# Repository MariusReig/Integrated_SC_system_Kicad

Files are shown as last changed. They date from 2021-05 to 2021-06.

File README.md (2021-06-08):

# Integrated_SC_system_Kicad
This repository contains the schematics and layout for an integrated supercapacitor system design.

Some changes is done in the schematic after the prototype was constructed. This includes:
- Removed schotky diode and auto-balancing in the cell balancing circuitry. 
- Adjusted cell-balancing resistance. 
- Adjusted pull-up resistor in the OVP. This is also done to the prototype.
- Charge and pre-charge gate-signal on isolated end is switched. 

Notes from testing of the prototype:
- The prototype is able to charge without any gatesignal through the pre-charge mosfet. Gatesignal is required to utilize charge and load. 
- The auto-balancing IC does not work as intended. Seems to be working for one cell of the two connected for each. Go back and check connections or use only resistor balancing. 
The design with balancing two-and-two cells is not great and needs work. Also caused the voltage potential over some odd-number cells to become negative. The voltage potential over the two first cells affected another, causing the even cell to receive more charge. A quick fix was to remove the IC and solder on 160ohm balancing resistance for each cell. The prototype was then balanced properly and tests was carried out. 
- The schotky diode was removed to test if it was a potential error-source. It was not. 
- The OVP circuit did not work. Since all 12 circuits are connected to the same 5V_ISO supply all will be pulled to ground unless all are active at the same time. The differential amplifier works as intended, but not the votlage detection IC. Tests on the IC can be carried out to check if it works as designed.

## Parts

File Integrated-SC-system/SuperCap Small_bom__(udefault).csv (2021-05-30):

Component | Description | Part | References | Value | Footprint | Quantity Per PCB | Datasheet | Mouser Part Number | Mouser Price/Stock | Manufacturer_Name | Height | Manufacturer_Part_Number | Arrow Part Number | Arrow Price/Stock
1 | Unpolarized capacitor | C | C2 C5 C11 C12 C15 | 100p | C_1206_3216Metric_Pad1.33x1.80mm_HandSolder | 5 | ~ | 581-12063A101FAT2A | https://no.mouser.com/ProductDetail/AVX/12063A101FAT2A?qs=Y1%2F2wzs%252B63syfZuGtnXFwA%3D%3D
2 | Unpolarized capacitor | C | C19 | 330p | C_1206_3216Metric_Pad1.33x1.80mm_HandSolder | 1 | ~ | 80-C1206C331F3HACTU | https://no.mouser.com/ProductDetail/KEMET/C1206C331F3HACTU?qs=W0yvOO0ixfE2Qm7oN9qcZQ%3D%3D
3 | Unpolarized capacitor | C | C14 | 430p | C_1206_3216Metric_Pad1.33x1.80mm_HandSolder | 1 | ~ | 77-VJ12A100V431J | https://no.mouser.com/ProductDetail/Vishay-Vitramon/VJ1206A431JXBAT/?qs=sbOXSeWPT5yYapLoCJrwWA%3D%3D
4 | Unpolarized capacitor | C | C6 | 470p | C_1206_3216Metric_Pad1.33x1.80mm_HandSolder | 1 | ~ | 80-C1206C471F5G | https://no.mouser.com/ProductDetail/KEMET/C1206C471F5GACTU?qs=slLRK711bwGFkpel8EAHvQ%3D%3D
5 | Unpolarized capacitor | C | C1 C4 C7 C9 C13 | 0.01u | C_1206_3216Metric_Pad1.33x1.80mm_HandSolder | 5 | ~ | 80-C1206C103F3GECAUT | https://no.mouser.com/ProductDetail/KEMET/C1206C103F3GECAUTO?qs=MLItCLRbWszn6w2I8I0T6g%3D%3D
6 | Unpolarized capacitor | C | C17 C20 C22 C36 C37 C38 C39 C40 C41 C42 C43 C44 C45 C46 C47 C48 C49 C50 C51 C52 C53 C54 C55 C56 C57 C58 C59 C60 C61 C62 C63 C64 C65 C66 C67 C68 C69 C70 C71 C72 C73 C74 C75 C76 C77 C78 C79 C80 C81 C82 | 0.1u | C_1206_3216Metric_Pad1.33x1.80mm_HandSolder | 50 | ~ | 80-C1206C104F5JACTU | https://no.mouser.com/ProductDetail/KEMET/C1206C104F5JAC7800?qs=gZXFycFWdAOIF48nFZgPGA%3D%3D
7 | Unpolarized capacitor | C | C3 C18 C21 C23 C83 C84 | 1u | C_1206_3216Metric_Pad1.33x1.80mm_HandSolder | 6 | ~ | 80-C1206C105J3R | https://no.mouser.com/ProductDetail/KEMET/C1206C105J3RACTU?qs=ET0bm%252B8TtG75uIhC3K7JNQ%3D%3D
8 | Unpolarized capacitor | C | C10 | 2.2u | C_1206_3216Metric_Pad1.33x1.80mm_HandSolder | 1 | ~ | 80-C1206C225J4RECLR | https://no.mouser.com/ProductDetail/KEMET/C1206C225J4REC7210?qs=55YtniHzbhAne4%2FiU8PHXw%3D%3D
9 | Unpolarized capacitor | C | C8 | 10u | C_1206_3216Metric_Pad1.33x1.80mm_HandSolder | 1 | ~ | 80-C1206C106J3RAUTO | https://no.mouser.com/ProductDetail/KEMET/C1206C106J3RACAUTO/
10 | Unpolarized capacitor | C | C16 | 22u | C_1206_3216Metric_Pad1.33x1.80mm_HandSolder | 1 | ~ | 80-C1206C226K8R7210 | https://no.mouser.com/ProductDetail/KEMET/C1206C226K8RAC7210?qs=rrS6PyfT74d338OvQfUspw%3D%3D
11 | Supercapacitors / Ultracapacitors 2.7V, 360F, snap-in | BCAP0360_P270_S18 | C24 C25 C26 C27 C28 C29 C30 C31 C32 C33 C34 C35 | BCAP0360_P270_S18 | BCAP0350P270S18 | 12 | https://componentsearchengine.com/Datasheets/1/BCAP0350 P270 S18.pdf | 723-BCAP0360P270S18 | https://www.mouser.co.uk/ProductDetail/Maxwell-Nesscap/BCAP0360-P270-S18?qs=W0yvOO0ixfGj2%2FVlgi3Wlw%3D%3D | Maxwell / Nesscap | 63 | BCAP0360 P270 S18
12 | ON SEMICONDUCTOR - FSV10100V - SCHOTTKY RECT, AEC-Q101, 100V, TO-277 | FSV10100V | D1 D2 D3 D4 D5 D6 D7 D8 D9 D10 D11 D12 | FSV10100V | FSV20100V | 12 | https://www.onsemi.com/pub/Collateral/FSV10100V-D.PDF | 512-FSV10100V | https://www.mouser.co.uk/ProductDetail/ON-Semiconductor-Fairchild/FSV10100V/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 | ON Semiconductor | 1.2 | FSV10100V | FSV10100V | https://www.arrow.com/en/products/fsv10100v/on-semiconductor
13 |  | PESD15VL2BT,215 | D13 | PESD15VL2BT,215 | SOT95P230X110-3N | 1 | http://uk.rs-online.com/web/p/products/1242372 | 771-PESD15VL2BT-T/R | https://www.mouser.co.uk/ProductDetail/Nexperia/PESD15VL2BT215?qs=LOCUfHb8d9vyDy2ag0hbbA%3D%3D | Nexperia | 1.1 | PESD15VL2BT,215 | PESD15VL2BT,215 | https://www.arrow.com/en/products/pesd15vl2bt215/nexperia
14 | NEXPERIA - PMEG2005EJ,115 - Schottky Rectifier, 20 V, 500 mA, Single, SOD-323F, 2 Pins, 390 mV | PMEG2005EJ,115 | D14 | PMEG2005EJ,115 | SODFL2512X80N | 1 | https://ms.componentsearchengine.com/Datasheets/2/PMEG2005EJ,115.pdf | 771-PMEG2005EJ115 | https://www.mouser.co.uk/ProductDetail/Nexperia/PMEG2005EJ115/?qs=LOCUfHb8d9uGellji4OYNw%3D%3D | Nexperia | 0.8 | PMEG2005EJ,115 | PMEG2005EJ,115 | https://www.arrow.com/en/products/pmeg2005ej115/nexperia
15 | Rectifiers 1.4A 200V | RS07D-HM3-08 | D15 D16 D17 | RS07D-HM3-08 | SODFL3718X108N | 3 | https://www.vishay.com/docs/85195/rs07bm.pdf | 78-RS07D-HM3-08 | https://www.mouser.co.uk/ProductDetail/Vishay-Semiconductors/RS07D-HM3-08?qs=7MVldsJ5UaweGTh7Nw6msg%3D%3D | Vishay | 1.08 | RS07D-HM3-08
16 | Ferrite Beads 1K OHM 25% | MMZ1608B102CTA00 | FB1 | MMZ1608B102CTA00 | BEADC1608X95N | 1 | https://product.tdk.com/info/en/catalog/datasheets/beads_commercial_signal_mmz1608_en.pdf | 810-MMZ1608B102CTA00 | https://www.mouser.co.uk/ProductDetail/TDK/MMZ1608B102CTA00/?qs=XCwcpc%2FLnas8CYC6iNc7Bw%3D%3D | TDK | 0.95 | MMZ1608B102CTA00 | MMZ1608B102CTA00 | https://www.arrow.com/en/products/mmz1608b102cta00/tdk
17 | MOSFET Dual SAB MOSFET ARRAY VT=2.10V | ALD910021SALI | IC1 IC2 IC3 IC4 IC5 IC6 | ALD910017SALI | SOIC127P600X175-8N | 6 | https://no.mouser.com/datasheet/2/8/ALD810017-464290.pdf | 585-ALD910017SALI | https://no.mouser.com/ProductDetail/Advanced-Linear-Devices/ALD910017SALI?qs=8qknGW3gdyEh4xI%2FfTwrJg%3D%3D | Advanced Linear Devices Inc. | 1.75 | ALD910017SALI
18 | +/-250 mV-Input, Low-Cost Basic Isolated Amplifier for Current Sensing | AMC1100DUBR | IC9 | AMC1100DUBR | SOP254P1040X485-8N | 1 | http://www.ti.com/lit/gpn/amc1100 | 595-AMC1100DUBR | https://www.mouser.co.uk/ProductDetail/Texas-Instruments/AMC1100DUBR?qs=2UFnnMkojnWfS8LYivgqyg%3D%3D | Texas Instruments | 4.85 | AMC1100DUBR | AMC1100DUBR | https://www.arrow.com/en/products/amc1100dubr/texas-instruments
19 | Standard Voltage Detectors: ROHM CMOS reset ICs provide low current consumption and high accuracy. The extensive lineup includes both Nch Open Drain and CMOS output types in a wide range of detection voltages (from 2.3V to 6.0V, in 0.1V steps), enabling selection of the ideal solution based on customer requirements. In addition, the entire series is of course both lead-free and RoHS-compliant. | BD4827G-TR | IC11 IC13 IC15 IC17 IC19 IC21 IC23 IC25 IC27 IC29 IC31 IC33 | BD4827G-TR | SOT95P280X125-5N | 12 | https://www.rohm.com/datasheet/BD4827G/bd48xxg-e | 755-BD4827G-TR | https://www.mouser.co.uk/ProductDetail/ROHM-Semiconductor/BD4827G-TR/?qs=4kLU8WoGk0v%252BBSXG6NYCpw%3D%3D | ROHM Semiconductor | 1.25 | BD4827G-TR
20 | Automotive, high speed, robust EMC six-channel digital isolator | ISO7760FQDBQQ1 | IC36 IC37 | ISO7760FQDBQQ1 | SOP64P600X175-16N | 2 | http://www.ti.com/lit/gpn/ISO7760-Q1 | 595-ISO7760FQDBQQ1 | https://www.mouser.co.uk/ProductDetail/Texas-Instruments/ISO7760FQDBQQ1/?qs=9r4v7xj2LnnpbSNyx8E%2F4g%3D%3D | Texas Instruments | 1.75 | ISO7760FQDBQQ1 | ISO7760FQDBQQ1 | https://www.arrow.com/en/products/iso7760fqdbqq1/texas-instruments
21 | LDO Regulator 5V 0.15A SOT23-5 LD2985BM50R, Low Dropout Voltage Regulator, 0.15A, 5 V, 2.5 16 Vin, 5-Pin SOT-23 | LD2985BM50R | IC7 | LD2985BM50R | SOT95P280X145-5N | 1 | http://www.st.com/st-web-ui/static/active/en/resource/technical/document/datasheet/CD00004963.pdf | 511-LD2985BM50 | https://www.mouser.co.uk/ProductDetail/STMicroelectronics/LD2985BM50R?qs=qfafhnxZRGbT%2F8H%2FfdRIaA%3D%3D | STMicroelectronics | 1.45 | LD2985BM50R | LD2985BM50R | https://www.arrow.com/en/products/ld2985bm50r/stmicroelectronics
22 | MICROCHIP - MIC5225-3.3YM5-TR - LDO, REG, 16VIN, 0.15A, 3.3V, 2%, 5SOT23 | MIC5225-3.3YM5-TR | IC8 | MIC5225-3.3YM5-TR | SOT95P280X145-5N | 1 | http://www.farnell.com/datasheets/1580469.pdf | 998-MIC5225-3.3YM5TR | https://www.mouser.co.uk/ProductDetail/Microchip-Technology-Micrel/MIC5225-33YM5-TR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 | Microchip | 1.45 | MIC5225-3.3YM5-TR | MIC5225-3.3YM5-TR | https://www.arrow.com/en/products/mic5225-3.3ym5-tr/microchip-technology
23 | 36-V, Precision, Rail-to-Rail Input Output, Low Offset Voltage Op Amp | OPA197IDR | IC10 IC12 IC14 IC16 IC18 IC20 IC22 IC24 IC26 IC28 IC30 IC32 | OPA197IDR | SOIC127P600X175-8N | 12 | http://www.ti.com/lit/gpn/opa197 | 595-OPA197IDR | https://www.mouser.co.uk/ProductDetail/Texas-Instruments/OPA197IDR?qs=gMfM3zrbS4ovW9KDi3YhFw%3D%3D | Texas Instruments | 1.75 | OPA197IDR | OPA197IDR | https://www.arrow.com/en/products/opa197idr/texas-instruments
24 | Logic Gates Automotive triple 3-input OR gates with Schmitt-trigger inputs 14-SOIC -40 to 125 | SN74HCS4075QDRQ1 | IC34 IC35 | SN74HCS4075QDRQ1 | SOIC127P600X175-14N | 2 | http://www.ti.com/lit/ds/symlink/sn74hcs4075-q1.pdf | 595-SN74HCS4075QDRQ1 | https://www.mouser.co.uk/ProductDetail/Texas-Instruments/SN74HCS4075QDRQ1/?qs=OTrKUuiFdkYJMjynp6BR6g%3D%3D | Texas Instruments | 1.75 | SN74HCS4075QDRQ1
25 | 4-A, 6-A, 3.0-kVRMS Isolated Dual-Channel Gate Driver | UCC21220AD | IC38 IC39 | UCC21220AD | SOIC127P600X175-16N | 2 | http://www.ti.com/lit/gpn/UCC21220A | 595-UCC21220AD | https://www.mouser.co.uk/ProductDetail/Texas-Instruments/UCC21220AD?qs=qSfuJ%252Bfl%2Fd6MGQx3F2Zl1A%3D%3D | Texas Instruments | 1.75 | UCC21220AD | UCC21220AD | https://www.arrow.com/en/products/ucc21220ad/texas-instruments
26 | Headers & Wire Housings CGrid VT Shrd Hdr w/Pg TIN 12Ckt | 15-47-7512 | J2 | 15-47-7512 | 15477512 | 1 | https://componentsearchengine.com/Datasheets/1/15-47-7512.pdf | 538-15-47-7512 | https://www.mouser.co.uk/ProductDetail/Molex/15-47-7512?qs=R6oKXucT%2FvSQ%252B3x6ERulsA%3D%3D | Molex | 11.18 | 15-47-7512
27 | Phoenix Contact, 3 Way PCB Terminal Block | 1717017 | J3 J4 | 1717017 | 1717017 | 2 | https://www.phoenixcontact.com/online/portal/gb/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 | 651-1717017 | https://www.mouser.co.uk/ProductDetail/Phoenix-Contact/1717017/?qs=F5EMLAvA7ICZj%2FuGqj9o7A%3D%3D | Phoenix Contact | 13.8 | 1717017
28 |  | 691322310006 | J1 | 691322310006 | SHDRRA6W80P0X381_1X6_2405X920X700P | 1 | https://componentsearchengine.com/Datasheets/1/691322310006.pdf | 710-691322310006 | https://www.mouser.co.uk/ProductDetail/Wurth-Elektronik/691322310006?qs=2kOmHSv6VfRfmtr%252BexeoYQ%3D%3D | Wurth Elektronik | 7 | 691322310006
29 | Standard LEDs - SMD 1206 Dome Lens LED Yellow- 590nm | APTD3216LSYCK | LED1 LED2 LED3 LED4 LED5 LED6 LED7 LED8 LED9 LED10 LED11 LED12 LED13 | APTD3216LSYCK | LEDC3216X200N | 13 | http://www.kingbrightusa.com/images/catalog/SPEC/APTD3216LSYCK.pdf | 604-APTD3216LSYCK | https://www.mouser.co.uk/ProductDetail/Kingbright/APTD3216LSYCK/?qs=AQlKX63v8RvoX%252BazwCMI3g%3D%3D | Kingbright | 2 | APTD3216LSYCK | APTD3216LSYCK | https://www.arrow.com/en/products/aptd3216lsyck/kingbright
30 | Low-noise, 350 mA, 410-kHz transformer driver for isolated power supplies | SN6501DBVR | PS1 | SN6501DBVR | SOT95P280X145-5N | 1 | http://www.ti.com/lit/gpn/sn6501 | 595-SN6501DBVR | https://www.mouser.co.uk/ProductDetail/Texas-Instruments/SN6501DBVR?qs=X2y4EmDJZOUH5QW1%2F6%2Fqfg%3D%3D | Texas Instruments | 1.45 | SN6501DBVR | SN6501DBVR | https://www.arrow.com/en/products/sn6501dbvr/texas-instruments
31 | 3-A 17V Step-down Converter Module with Integrated Inductor | TPS82130SILT | PS2 | TPS82130SILT | TPS82130SILT | 1 | http://www.ti.com/lit/gpn/tps82130 | 595-TPS82130SILT | https://www.mouser.co.uk/ProductDetail/Texas-Instruments/TPS82130SILT/?qs=diC8vqfyxkr0HeHAfBUGmQ%3D%3D | Texas Instruments | 1 | TPS82130SILT | TPS82130SILT | https://www.arrow.com/en/products/tps82130silt/texas-instruments
32 | MOSFET TRENCH <= 40V | BSZ024N04LS6ATMA1 | Q1 Q2 Q3 | BSZ024N04LS6ATMA1 | BSZ024N04LS6ATMA1 | 3 | https://hu.mouser.com/datasheet/2/196/Infineon-BSZ024N04LS6-DS-v02_00-EN-1840560.pdf | 726-BSZ024N04LS6ATMA | https://www.mouser.co.uk/ProductDetail/Infineon-Technologies/BSZ024N04LS6ATMA1/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 | Infineon | 1.1 | BSZ024N04LS6ATMA1 | BSZ024N04LS6ATMA1 | https://www.arrow.com/en/products/bsz024n04ls6atma1/infineon-technologies-ag
33 | Resistor | R | R28 | 3.16 | R_1206_3216Metric_Pad1.30x1.75mm_HandSolder | 1 | ~ | 71-CRCW12063R16FKEA | https://no.mouser.com/ProductDetail/Vishay-Dale/CRCW12063R16FKEA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
34 | Resistor | R | R34 R35 | 12 | R_1206_3216Metric_Pad1.30x1.75mm_HandSolder | 2 | ~ | 603-RT1206BRD0712RL | https://no.mouser.com/ProductDetail/Yageo/RT1206BRD0712RL?qs=sGAEpiMZZMvdGkrng054t98Xz4DA4UW4l7oCtBzqUUM%3D
35 | Resistor | R | R131 | 30 | TO-263-2_TabPin1 | 1 | https://no.mouser.com/datasheet/2/303/AP750-1-34.161-1218743.pdf | 284-AP75025RF | https://no.mouser.com/ProductDetail/ARCOL-Ohmite/AP750-25R-F?qs=W0yvOO0ixfF%252BYHve3Lifqw%3D%3D |  |  | AP750 25R F
36 | Resistor | R | R29 R30 R31 R32 | 59.7 | R_1206_3216Metric_Pad1.30x1.75mm_HandSolder | 4 | ~ | 660-RN732BTTD5972B50 | https://no.mouser.com/ProductDetail/KOA-Speer/RN732BTTD5972B50
37 | Resistor | R | R1 R2 R3 R4 R5 R6 R7 R8 R9 R10 R11 R12 R13 R14 R15 R16 R17 R18 R19 R20 R21 R22 R23 R24 R44 R51 R58 R65 R72 R79 R86 R93 R100 R107 R114 R121 | 400 | R_1206_3216Metric_Pad1.30x1.75mm_HandSolder | 36 | ~ | 660-RN732BTTD4000B25 | https://no.mouser.com/ProductDetail/KOA-Speer/RN732BTTD4000B25
38 | Resistor | R | R33 R43 R50 R57 R64 R71 R78 R85 R92 R99 R106 R113 R120 | 1k | R_1206_3216Metric_Pad1.30x1.75mm_HandSolder | 13 | ~ | 660-RN73H2TD1001B10 | https://no.mouser.com/ProductDetail/KOA-Speer/RN73H2BTTD1001B10
39 | Resistor | R | R38 R39 R40 R41 R42 R45 R46 R47 R48 R49 R52 R53 R54 R55 R56 R59 R60 R61 R62 R63 R66 R67 R68 R69 R70 R73 R74 R75 R76 R77 R80 R81 R82 R83 R84 R87 R88 R89 R90 R91 R94 R95 R96 R97 R98 R101 R102 R103 R104 R105 R108 R109 R110 R111 R112 R115 R116 R117 R118 R119 | 10k | R_1206_3216Metric_Pad1.30x1.75mm_HandSolder | 60 | ~ | 660-RN73H2BTD1002B10 | https://no.mouser.com/ProductDetail/KOA-Speer/RN73H2BTTD1002B10
40 | Resistor | R | R25 R27 | 100k | R_1206_3216Metric_Pad1.30x1.75mm_HandSolder | 2 | ~ | 660-RN73R2BTD1003B25 | https://no.mouser.com/ProductDetail/KOA-Speer/RN73R2BTTD1003B25
41 | Resistor | R | R26 | 523k | R_1206_3216Metric_Pad1.30x1.75mm_HandSolder | 1 | ~ | 667-ERA-8AEB5233V | https://no.mouser.com/ProductDetail/Panasonic/ERA-8AEB5233V?qs=sGAEpiMZZMvdGkrng054t5mej2KPdPuFNNFHojpmzKg%3D
42 | Resistor | R | R36 R37 R125 R126 R127 R128 R129 R130 | R | R_1206_3216Metric_Pad1.30x1.75mm_HandSolder | 8 | ~ | 660-RN73H2TD1001B10 | https://no.mouser.com/ProductDetail/KOA-Speer/RN73H2BTTD1001B10
43 | Resistor | R | R122 R123 R124 | rc | R_1206_3216Metric_Pad1.30x1.75mm_HandSolder | 3 | ~ | 71-RCS120651R0FKEA | https://no.mouser.com/ProductDetail/Vishay-Dale/RCS120651R0FKEA/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
44 | Power Transformers MID-SN6501 TI Driver Toroid .475mH 3.3VDC | 760390015 | T1 | 760390015 | 760390015 | 1 | https://katalog.we-online.com/ctm/datasheet/760390015.pdf | 710-760390015 | https://www.mouser.co.uk/ProductDetail/Wurth-Elektronik-Midcom/760390015?qs=wElim4iM2pjOQCmk%252B8YbFA%3D%3D | Wurth Elektronik / Midcom |  | 760390015
45 | 50A Unidirectional Hall-Effect Current Sensor, +5.0V supply, 60mV/A, CB-5 PFF | ACS758xCB-050U-PFF | U1 | ACS758LCB-050B-PFF-T | Allegro_CB_PFF | 1 | http://www.allegromicro.com/~/media/Files/Datasheets/ACS758-Datasheet.ashx?la=en
46 | Diodes Inc DFLZ6V2-7 Zener Diode, 6.2V 5% 1 W SMT 2-Pin PowerDI 123 | DFLZ6V2-7 | Z1 | DFLZ6V2-7 | DFLZ6V87 | 1 | https://www.diodes.com/assets/Datasheets/ds30464.pdf | 621-DFLZ6V2-7 | https://www.mouser.co.uk/ProductDetail/Diodes-Incorporated/DFLZ6V2-7/?qs=mQbszxtPdlMwrqI91DAGTw%3D%3D | Diodes Inc. | 1 | DFLZ6V2-7 | DFLZ6V2-7 | https://www.arrow.com/en/products/dflz6v2-7/diodes-incorporated
Component Groups: | 46
Component Count: | 297
Fitted Components: | 297
Number of PCBs: | 1
Total components: | 297
Schematic Version:
Schematic Date:
PCB Variant: | udefault
BoM Date: | 14.03.2021 20:53:36
Schematic Source: | SuperCap Small.sch
KiCad Version: | Eeschema (5.1.7)-1

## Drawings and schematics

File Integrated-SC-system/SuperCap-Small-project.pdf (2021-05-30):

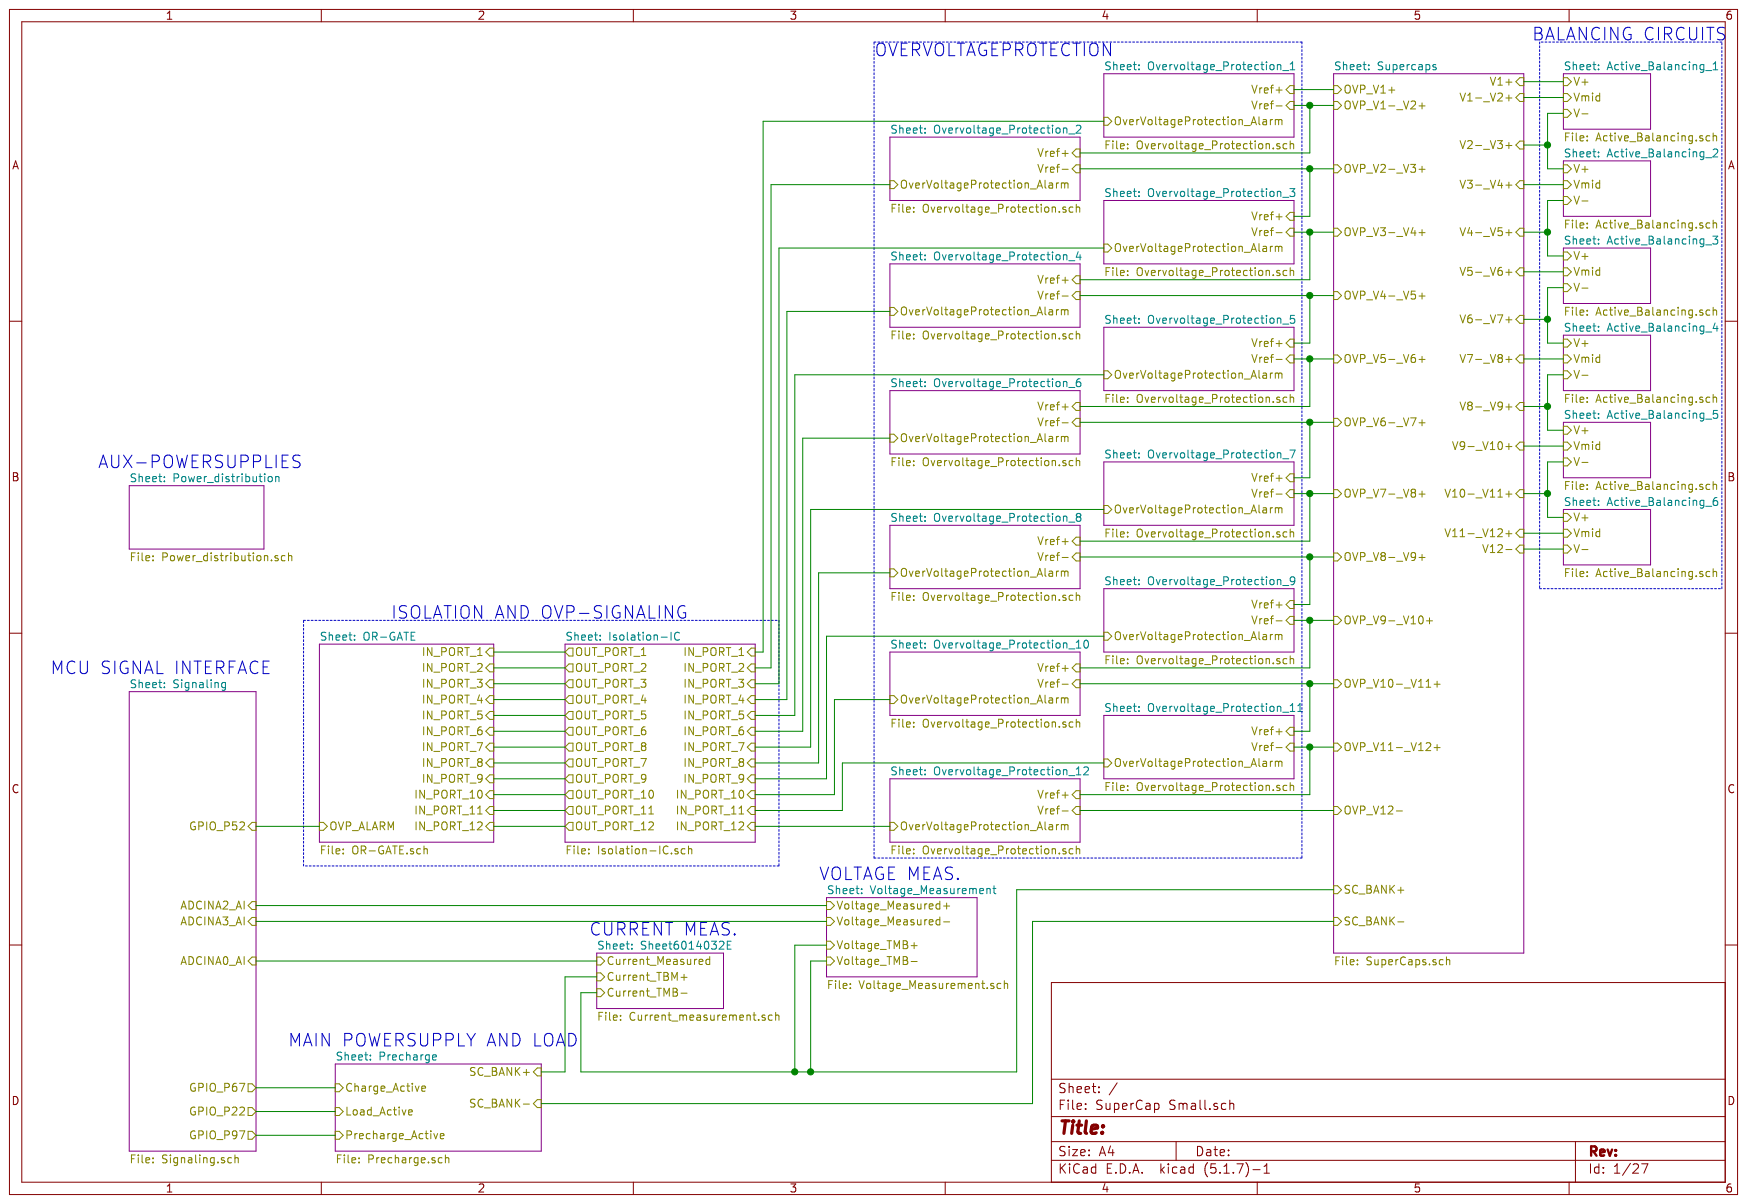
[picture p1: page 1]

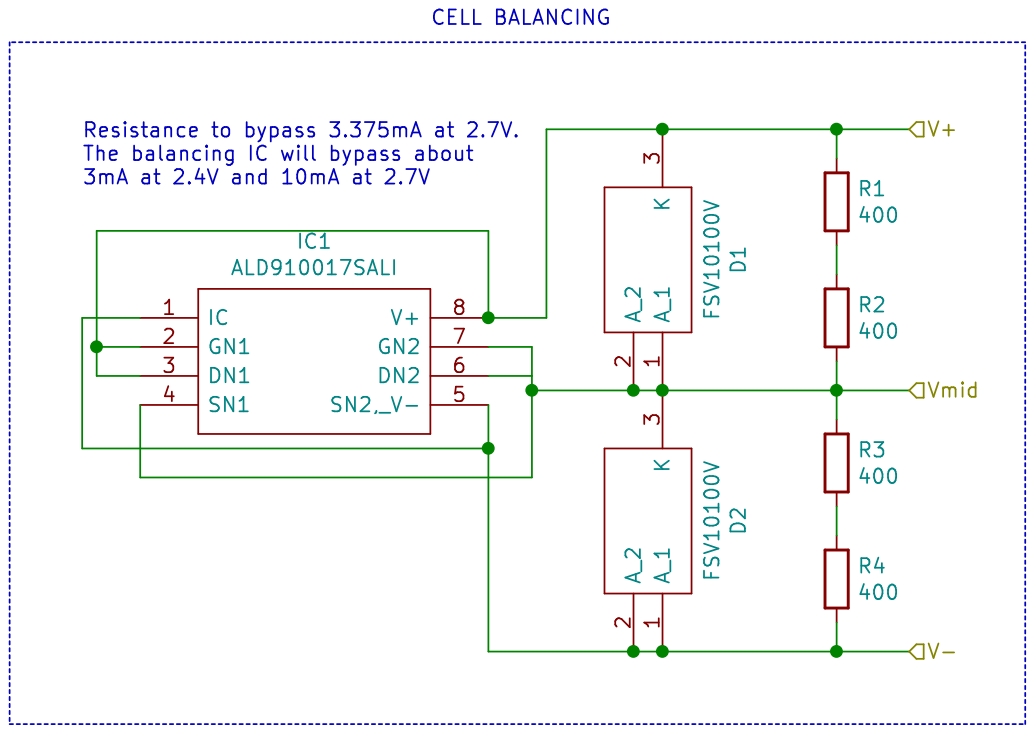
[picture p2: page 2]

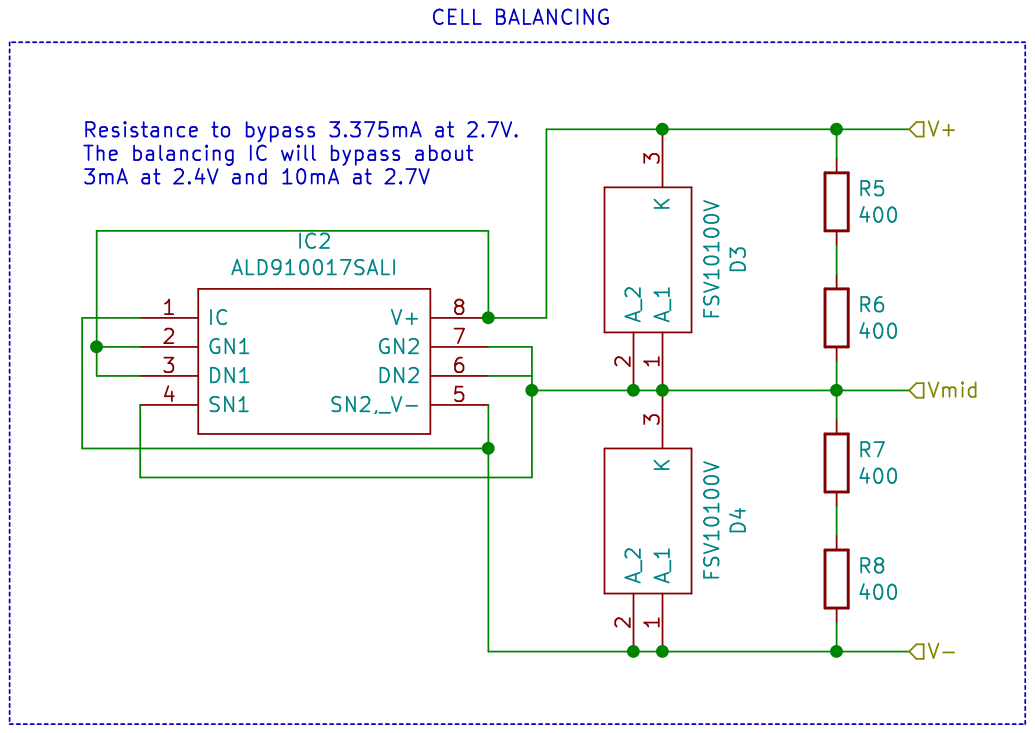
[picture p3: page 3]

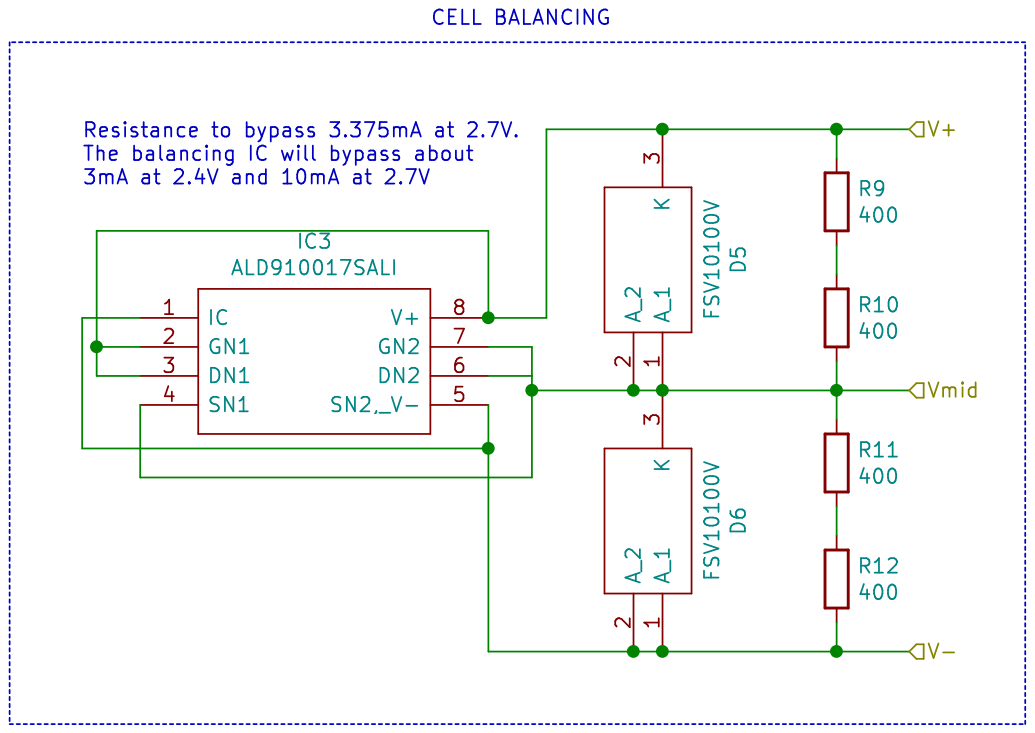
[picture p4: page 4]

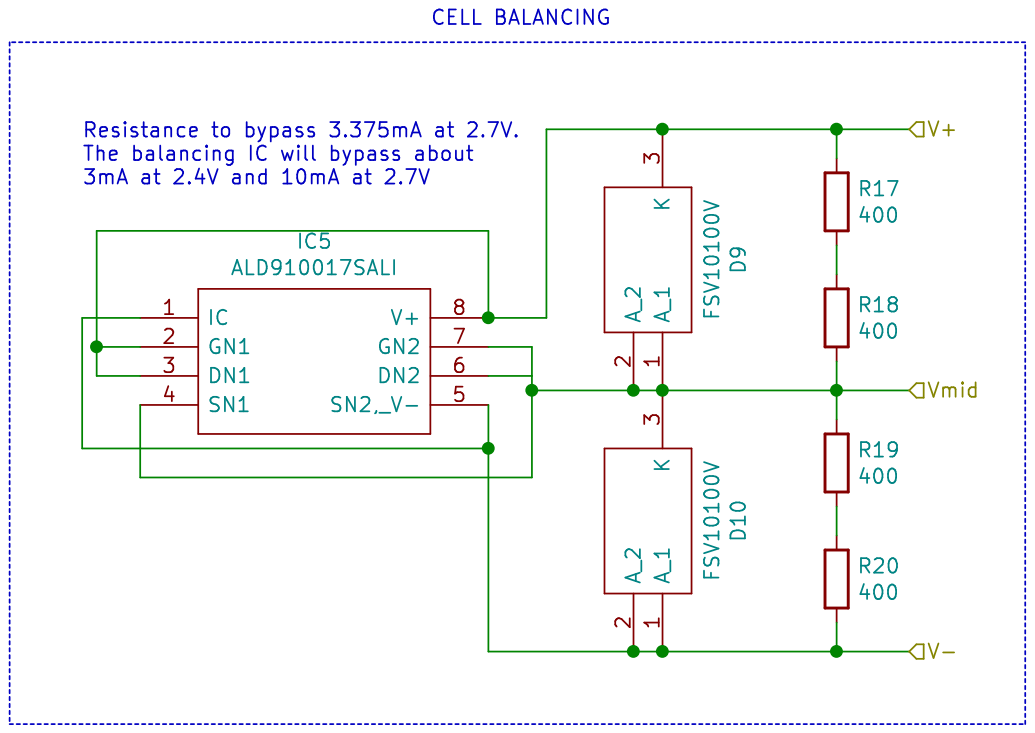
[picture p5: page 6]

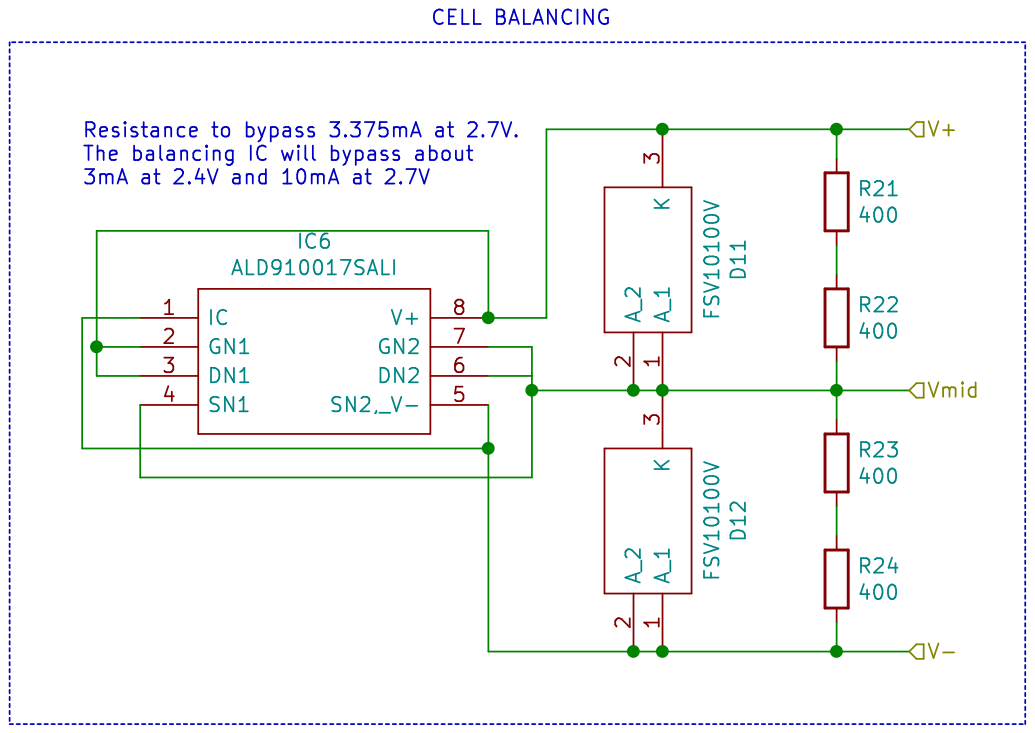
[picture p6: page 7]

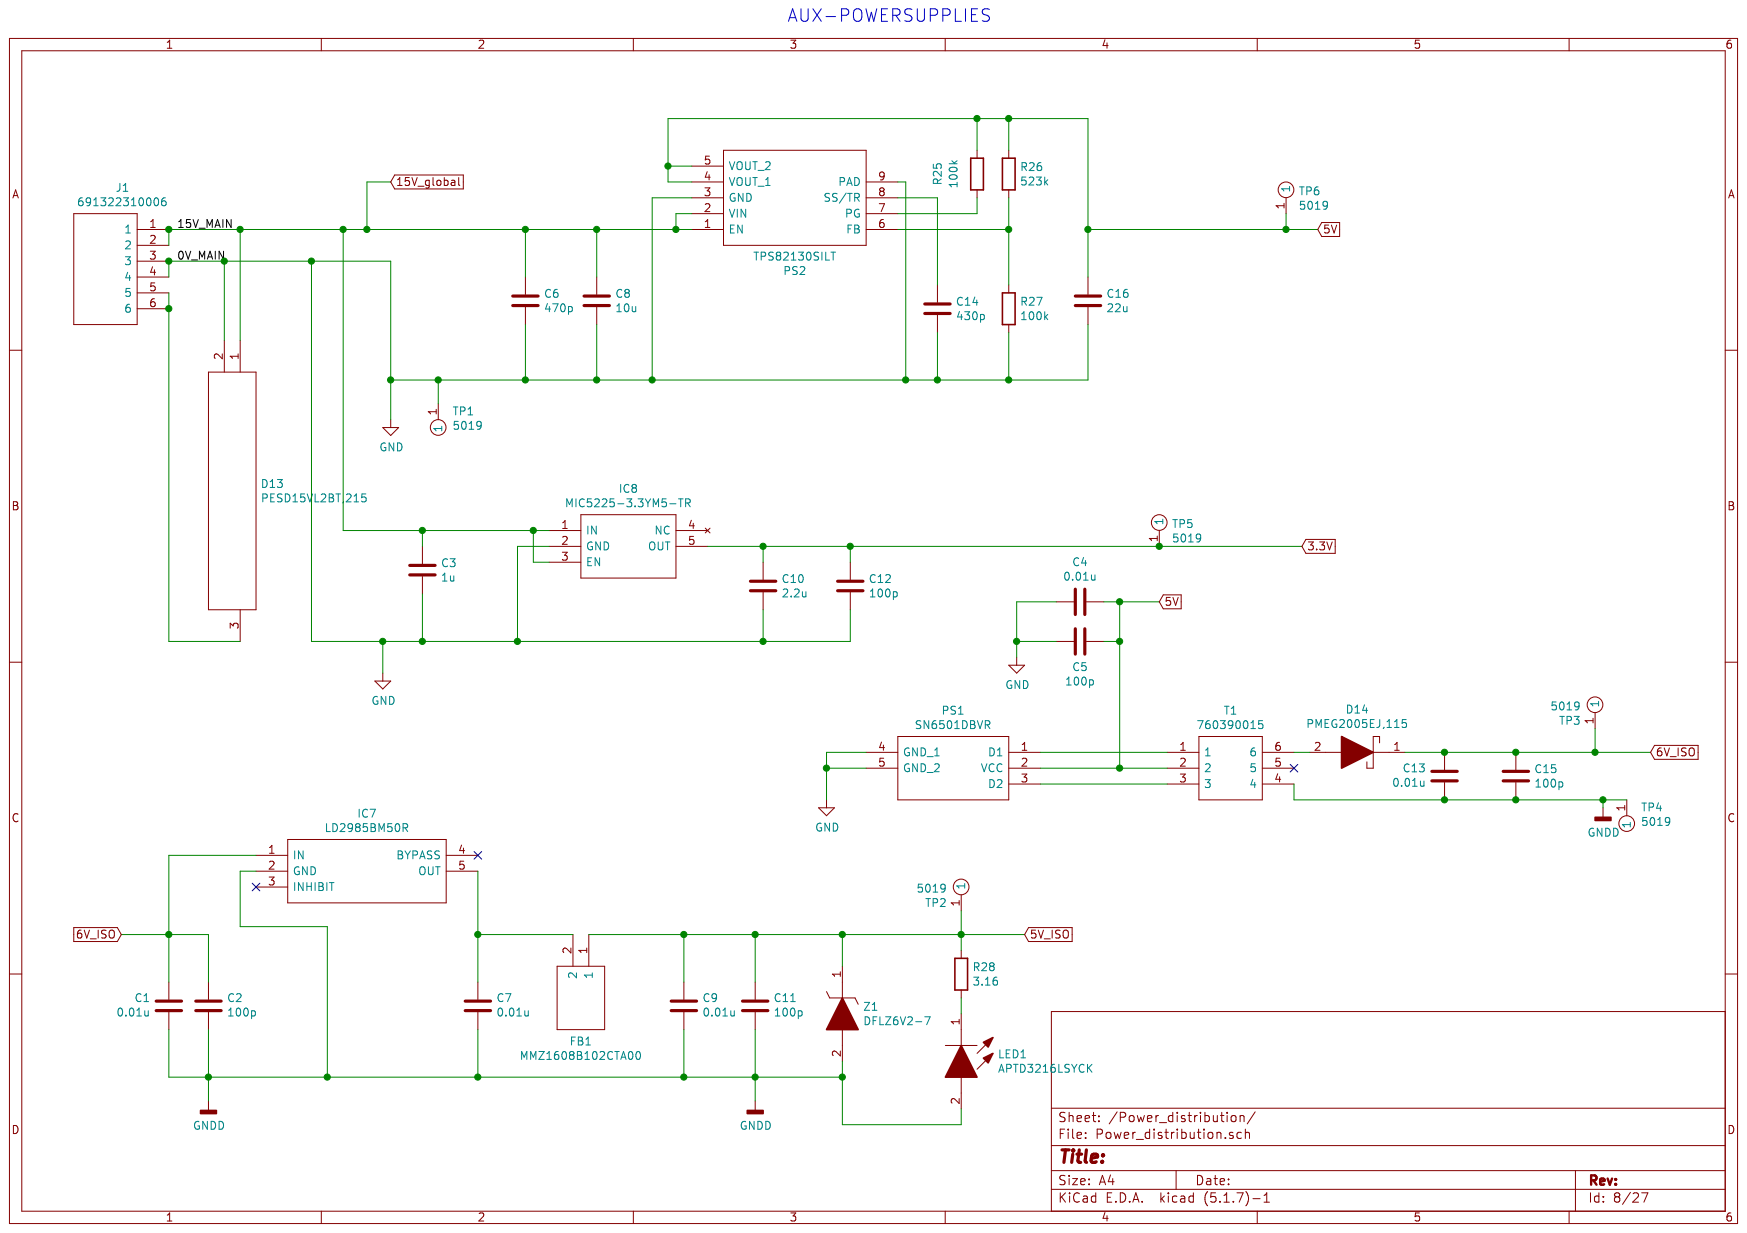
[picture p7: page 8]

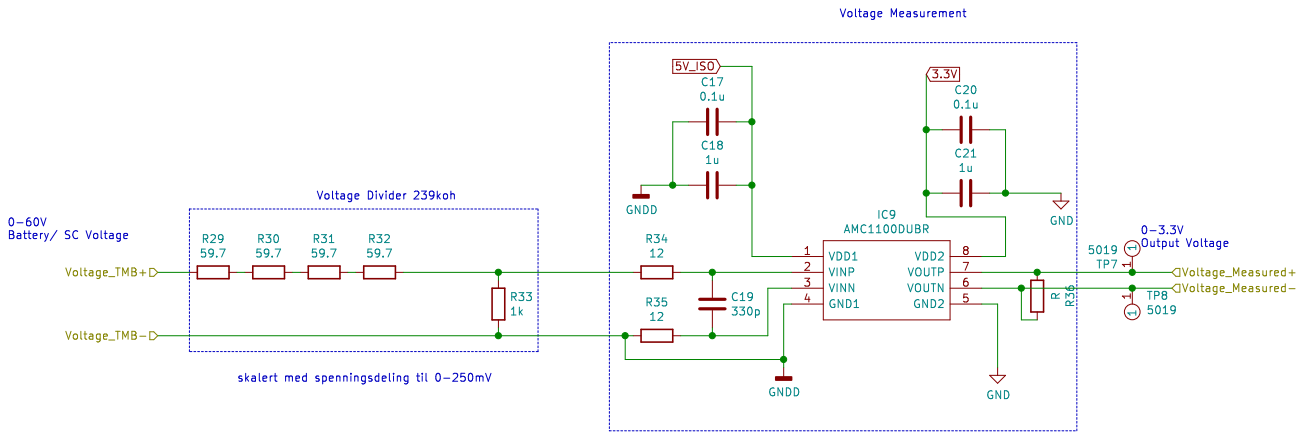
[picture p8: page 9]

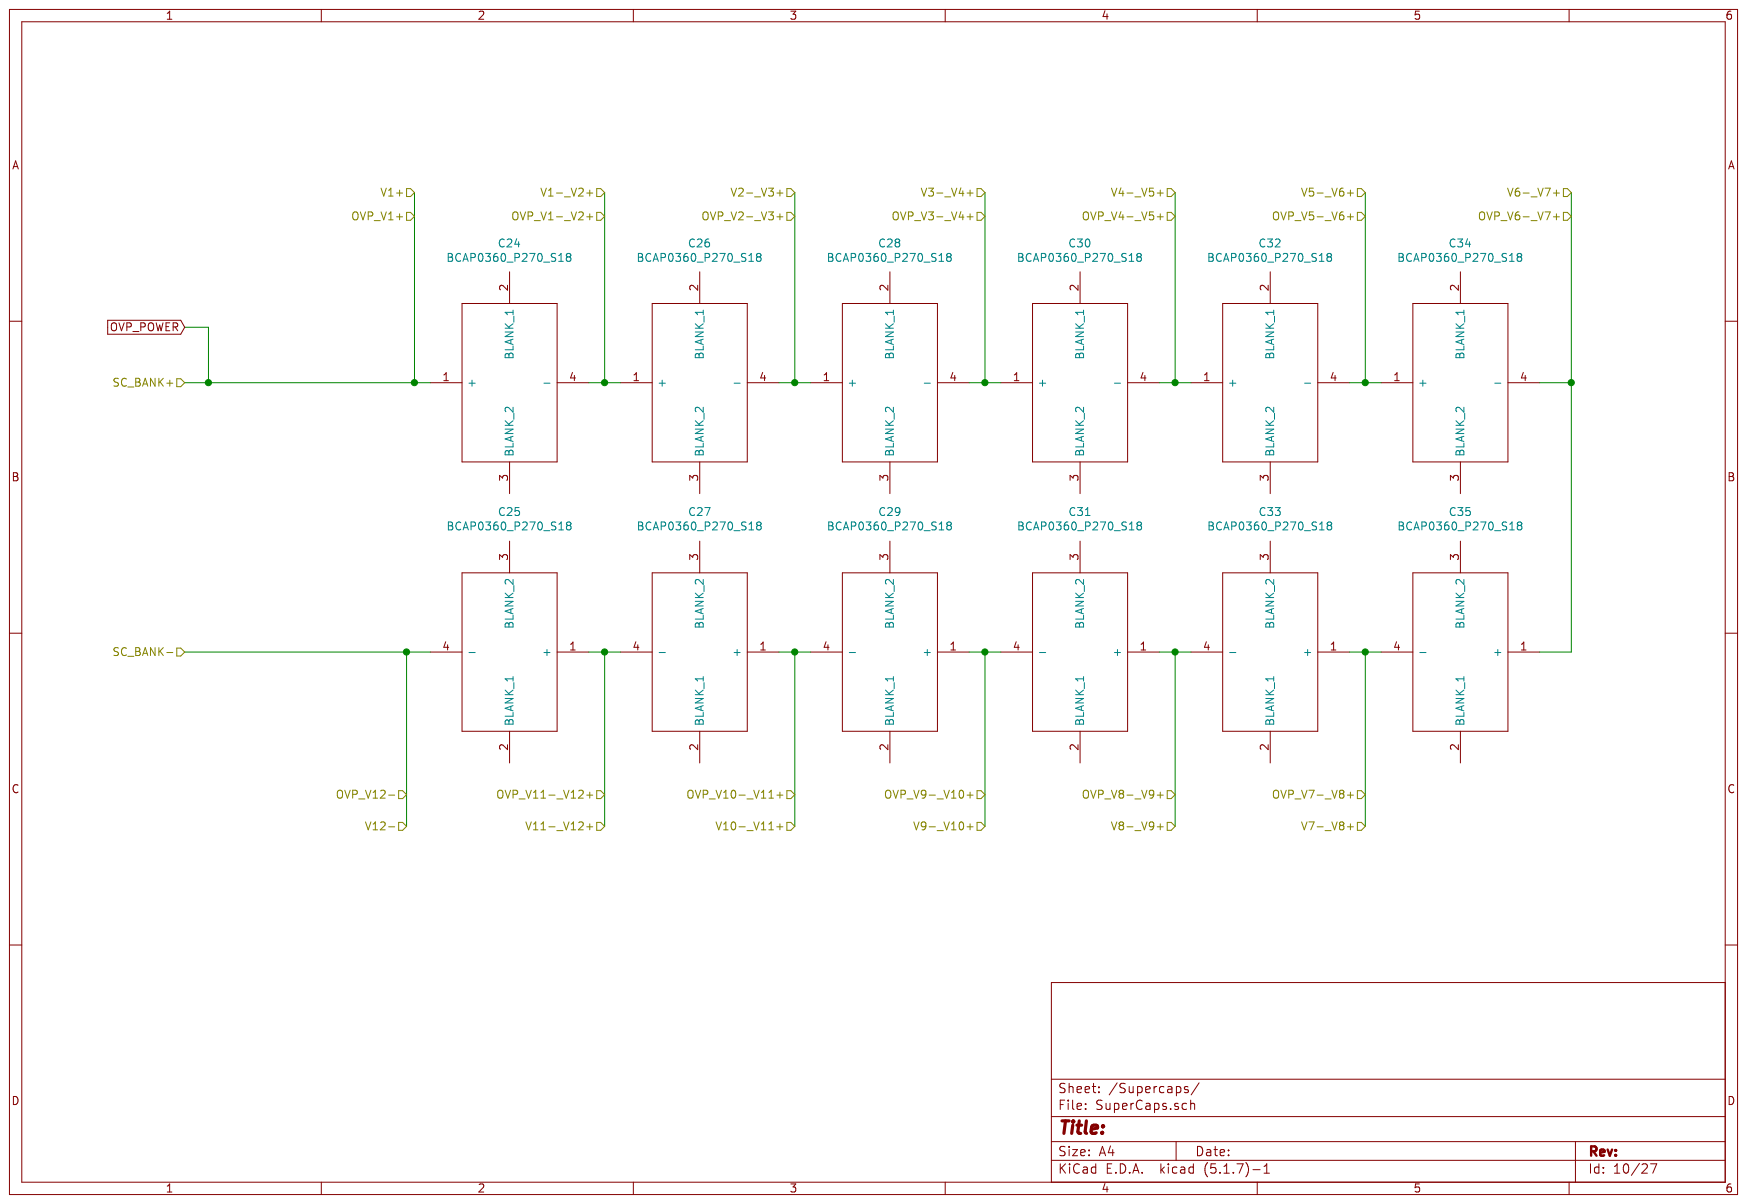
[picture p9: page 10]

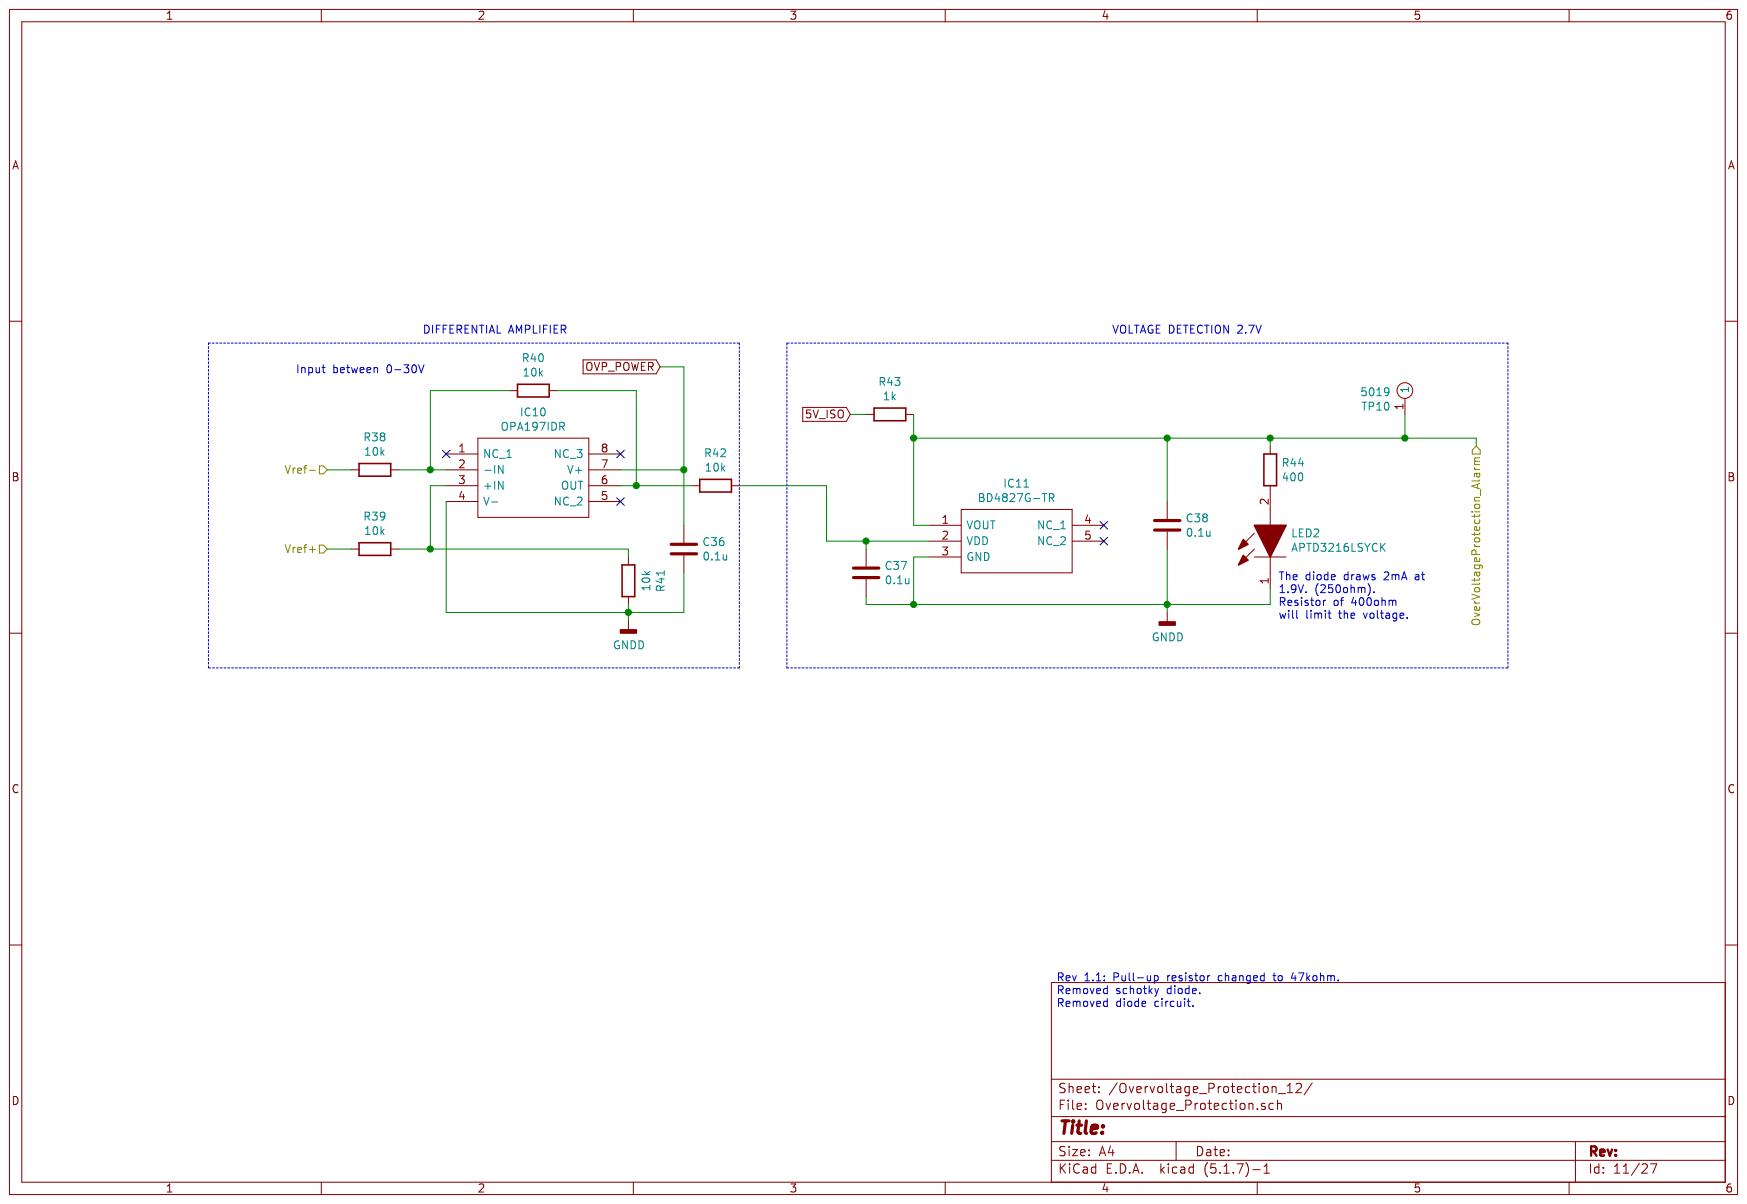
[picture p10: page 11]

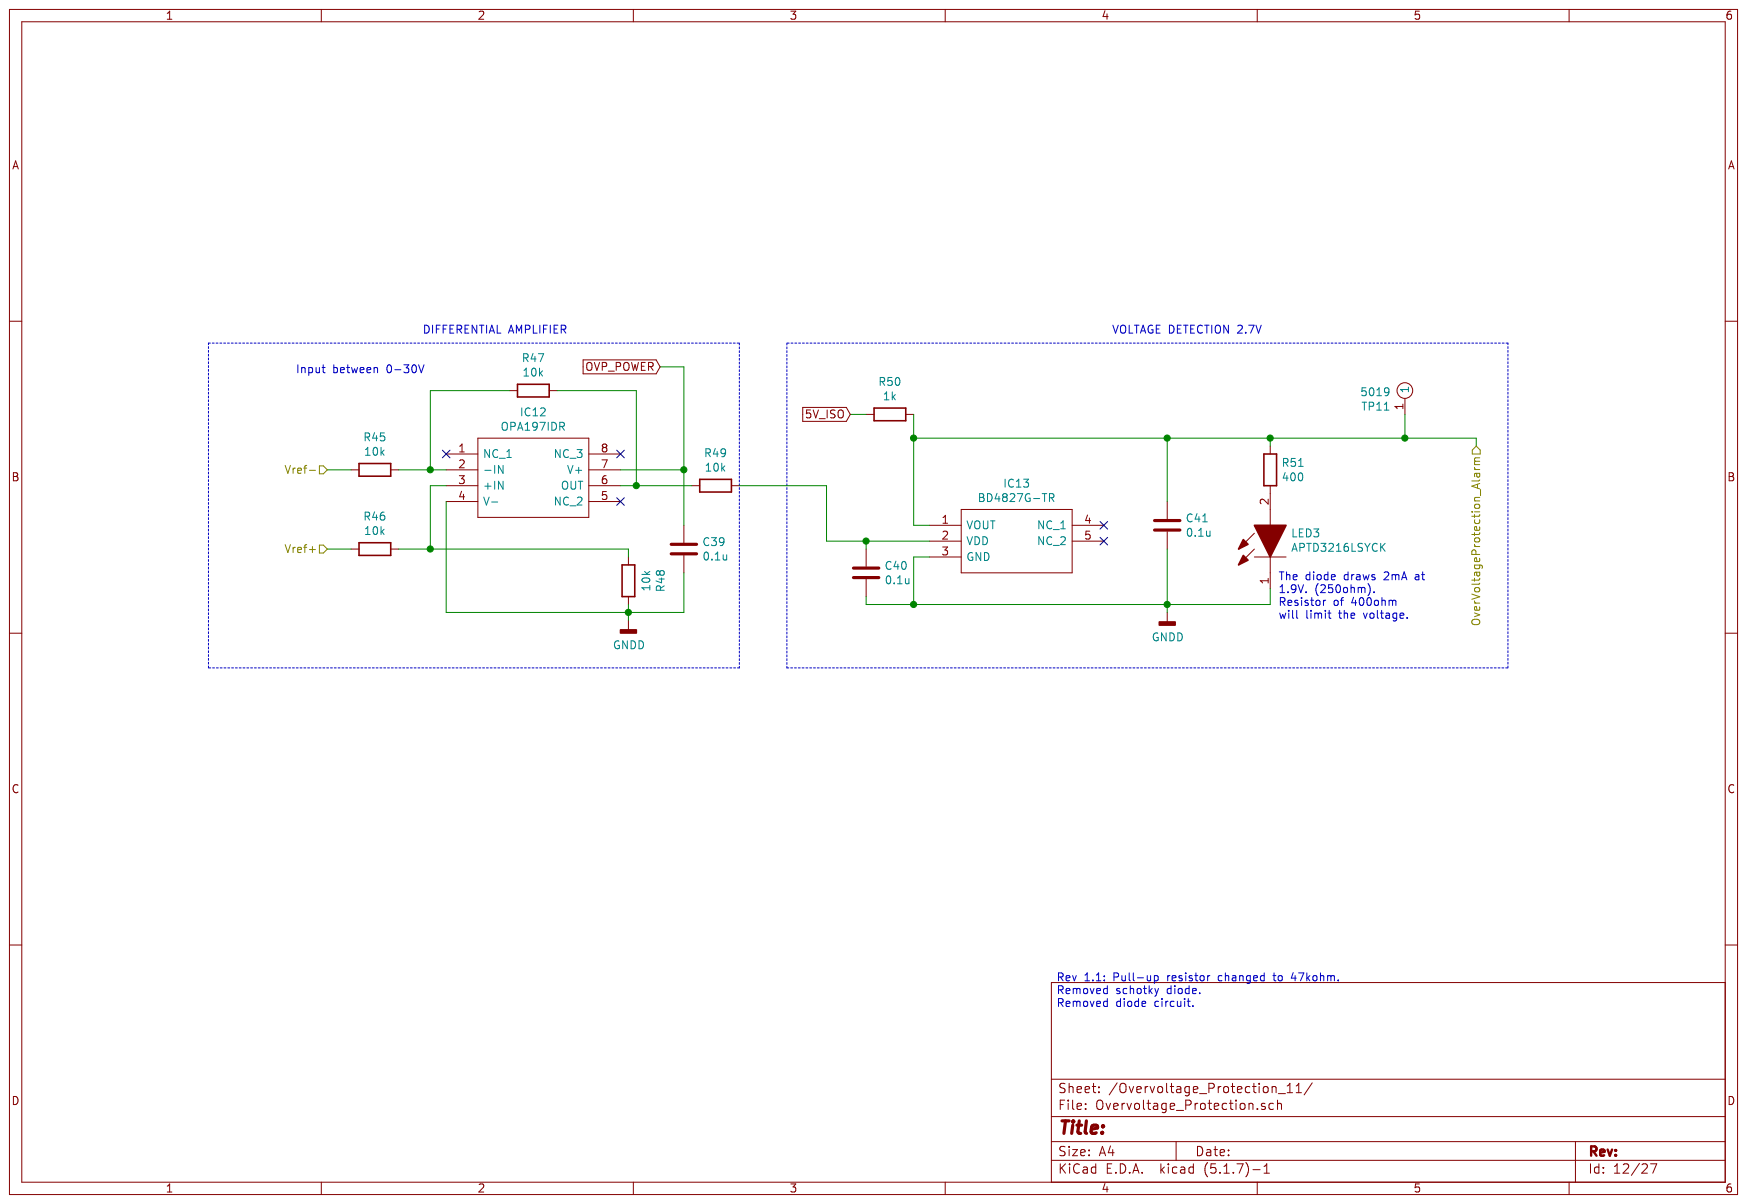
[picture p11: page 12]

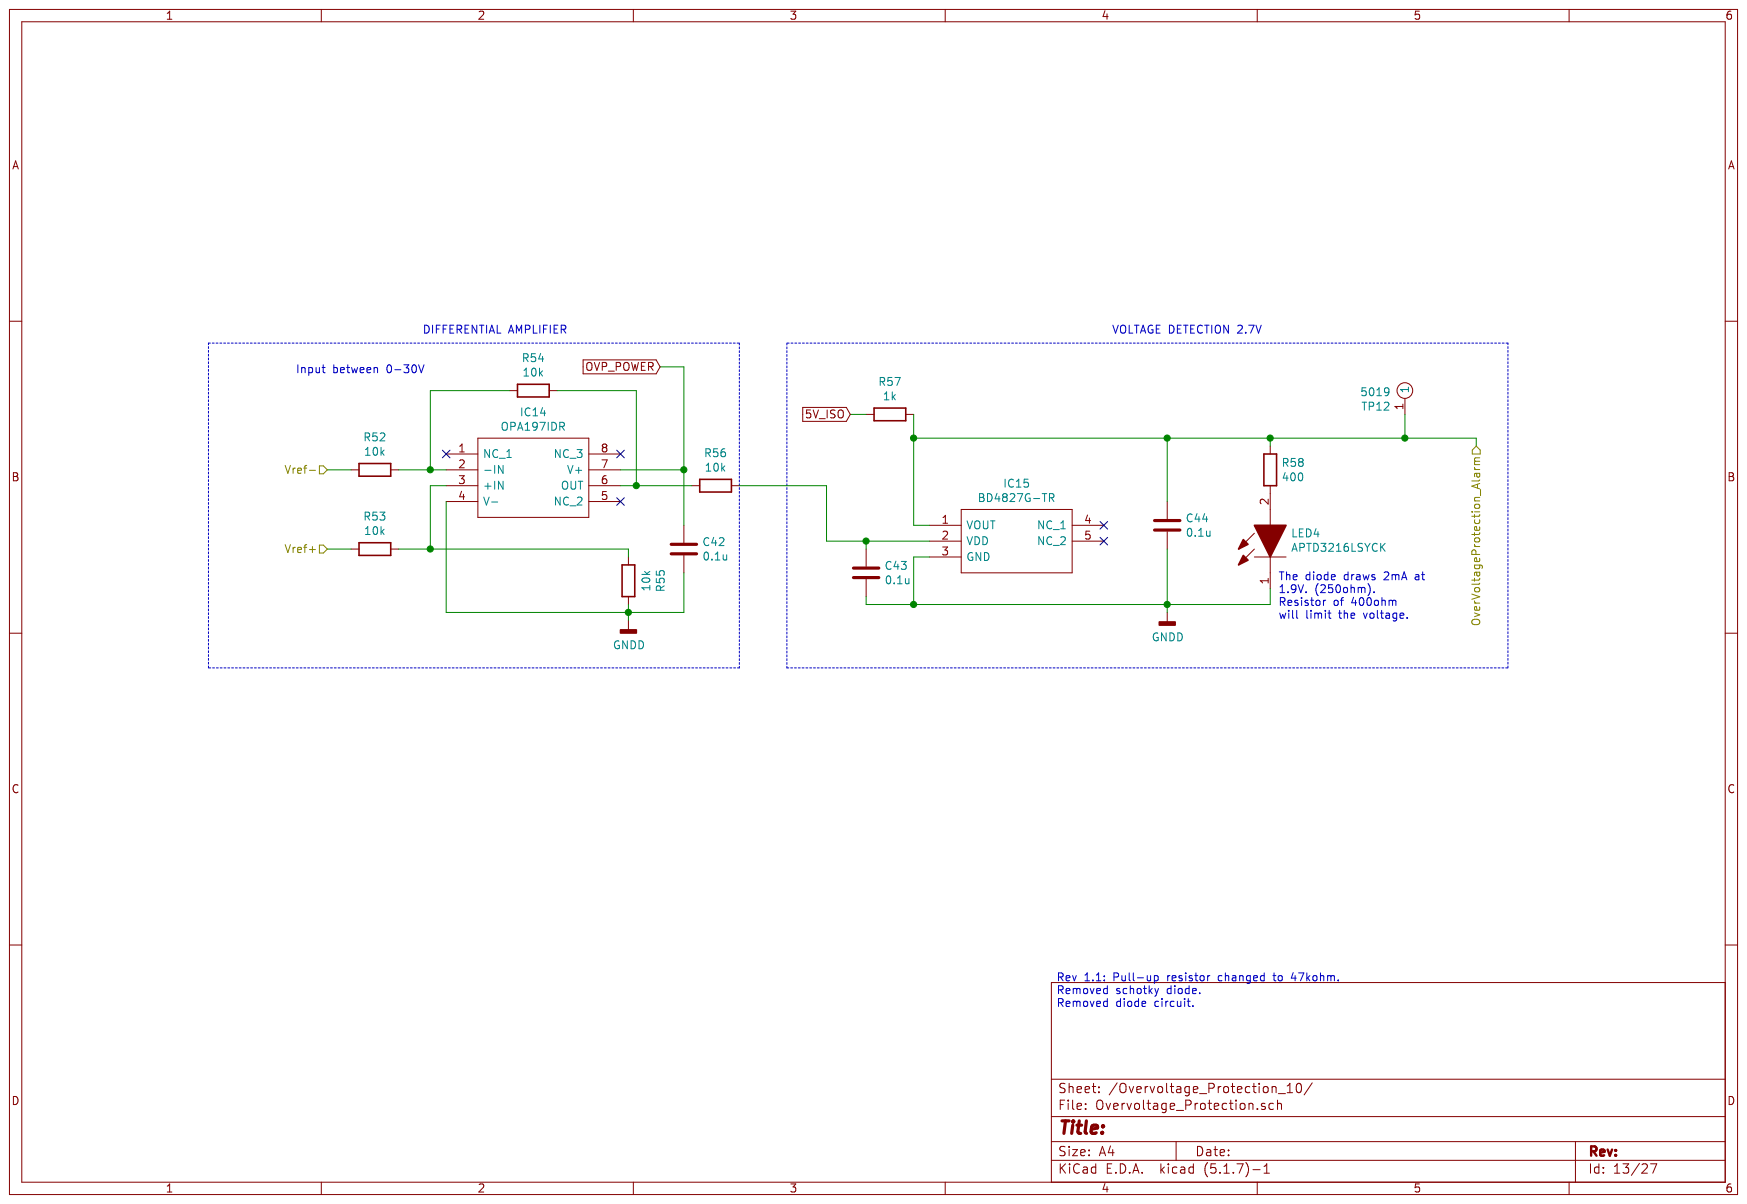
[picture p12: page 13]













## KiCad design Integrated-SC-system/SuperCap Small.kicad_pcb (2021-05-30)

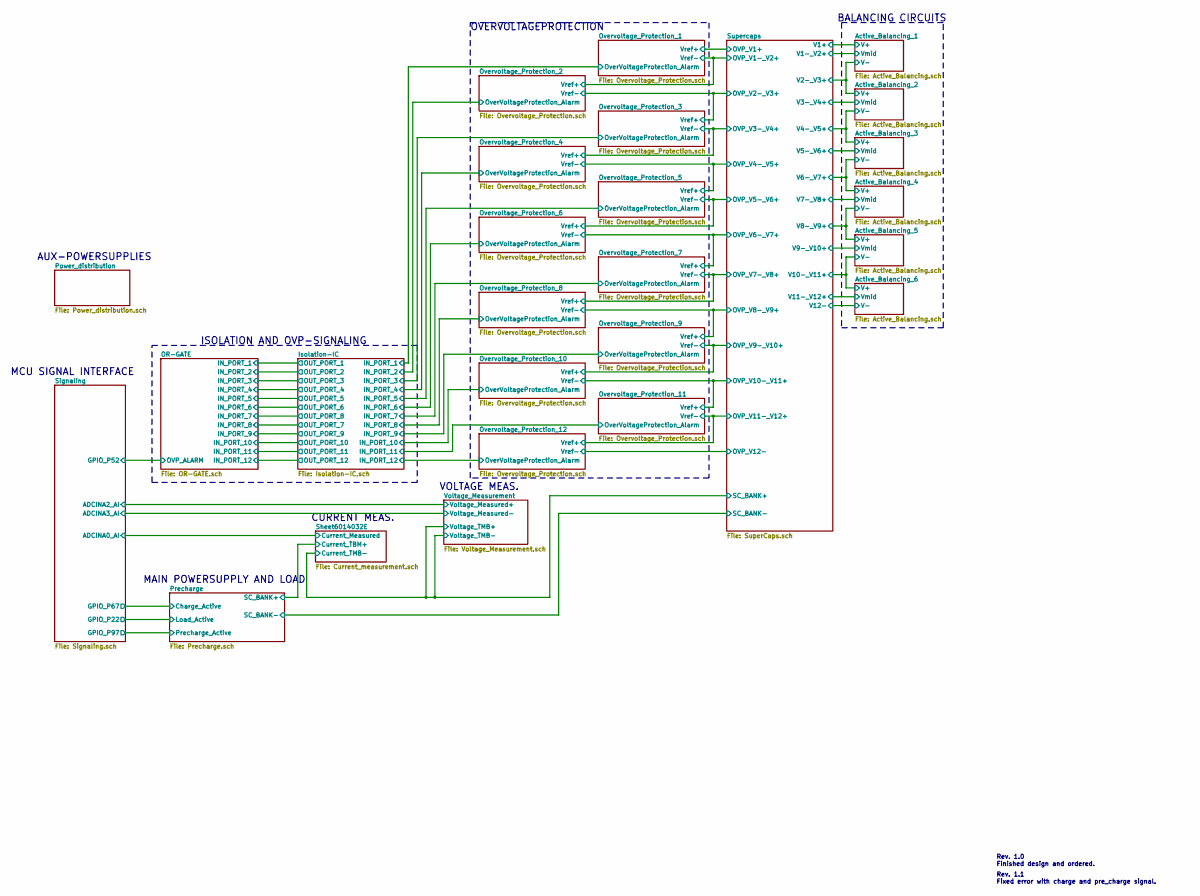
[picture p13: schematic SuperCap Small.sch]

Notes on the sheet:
Rev. 1.1 Fixed error with charge and pre_charge signal.
Rev. 1.0 Finished design and ordered.
OVERVOLTAGEPROTECTION
BALANCING CIRCUITS
ISOLATION AND OVP-SIGNALING
AUX-POWERSUPPLIES
MAIN POWERSUPPLY AND LOAD
CURRENT MEAS.
VOLTAGE MEAS.
MCU SIGNAL INTERFACE

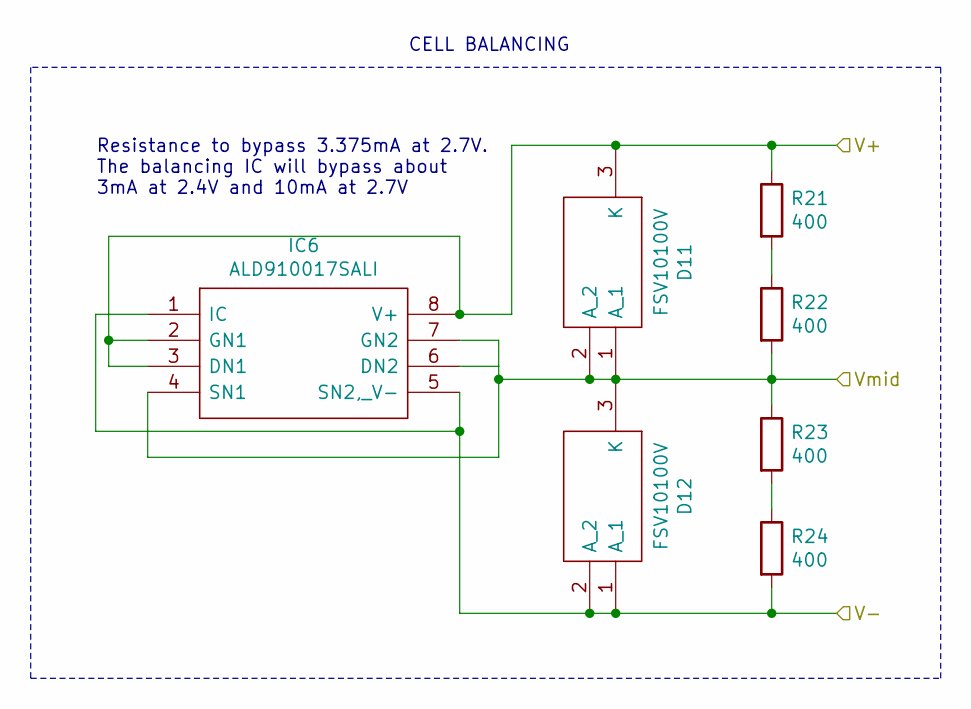
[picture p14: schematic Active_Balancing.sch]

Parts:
D1, D2: FSV10100V; FSV20100V; Manufacturer_Part_Number FSV10100V; Mouser Part Number 512-FSV10100V
IC1: ALD910017SALI; SOIC127P600X175-8N; Manufacturer_Part_Number ALD910017SALI; Mouser Part Number 585-ALD910017SALI
R1, R2, R3, R4: 400; R_1206_3216Metric_Pad1.30x1.75mm_HandSolder; Mouser Part Number 660-RN732BTTD4000B25

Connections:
/Supercaps/OVP_V1-_V2+: D1.1 (A_1), D1.2 (A_2), D2.3 (K), IC1.4 (SN1), IC1.6 (DN2), IC1.7 (GN2), R2.2, R3.1; also elsewhere on the board
/Supercaps/OVP_V2-_V3+: D2.1 (A_1), D2.2 (A_2), IC1.1 (IC), IC1.5 (SN2,_V-), R4.2; also elsewhere on the board
unnamed: R1.2, R2.1
unnamed: R3.2, R4.1
OVP_POWER: D1.3 (K), IC1.2 (GN1), IC1.3 (DN1), IC1.8 (V+), R1.1; also elsewhere on the board

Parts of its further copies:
D3, D4, D5, D6, D7, D8, D9, D10, D11, D12: FSV10100V; FSV20100V; Manufacturer_Part_Number FSV10100V; Mouser Part Number 512-FSV10100V
IC2, IC3, IC4, IC5, IC6: ALD910017SALI; SOIC127P600X175-8N; Manufacturer_Part_Number ALD910017SALI; Mouser Part Number 585-ALD910017SALI
R5, R6, R7, R8, R9, R10, R11, R12, R13, R14, R15, R16, R17, R18, R19, R20, R21, R22, R23, R24: 400; R_1206_3216Metric_Pad1.30x1.75mm_HandSolder; Mouser Part Number 660-RN732BTTD4000B25

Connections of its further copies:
/Supercaps/OVP_V2-_V3+: D3.3 (K), IC2.2 (GN1), IC2.3 (DN1), IC2.8 (V+), R5.1; also elsewhere on the board
/Supercaps/OVP_V3-_V4+: D3.1 (A_1), D3.2 (A_2), D4.3 (K), IC2.4 (SN1), IC2.6 (DN2), IC2.7 (GN2), R6.2, R7.1; also elsewhere on the board
/Supercaps/OVP_V4-_V5+: D4.1 (A_1), D4.2 (A_2), D5.3 (K), IC2.1 (IC), IC2.5 (SN2,_V-), IC3.2 (GN1), IC3.3 (DN1), IC3.8 (V+), R8.2, R9.1; also elsewhere on the board
/Supercaps/OVP_V5-_V6+: D5.1 (A_1), D5.2 (A_2), D6.3 (K), IC3.4 (SN1), IC3.6 (DN2), IC3.7 (GN2), R10.2, R11.1; also elsewhere on the board
/Supercaps/OVP_V6-_V7+: D6.1 (A_1), D6.2 (A_2), D11.3 (K), IC3.1 (IC), IC3.5 (SN2,_V-), IC6.2 (GN1), IC6.3 (DN1), IC6.8 (V+), R12.2, R21.1; also elsewhere on the board
/Supercaps/OVP_V7-_V8+: D11.1 (A_1), D11.2 (A_2), D12.3 (K), IC6.4 (SN1), IC6.6 (DN2), IC6.7 (GN2), R22.2, R23.1; also elsewhere on the board
/Supercaps/OVP_V8-_V9+: D9.3 (K), D12.1 (A_1), D12.2 (A_2), IC5.2 (GN1), IC5.3 (DN1), IC5.8 (V+), IC6.1 (IC), IC6.5 (SN2,_V-), R17.1, R24.2; also elsewhere on the board
/Supercaps/OVP_V9-_V10+: D9.1 (A_1), D9.2 (A_2), D10.3 (K), IC5.4 (SN1), IC5.6 (DN2), IC5.7 (GN2), R18.2, R19.1; also elsewhere on the board
/Supercaps/OVP_V10-_V11+: D7.3 (K), D10.1 (A_1), D10.2 (A_2), IC4.2 (GN1), IC4.3 (DN1), IC4.8 (V+), IC5.1 (IC), IC5.5 (SN2,_V-), R13.1, R20.2; also elsewhere on the board
/Supercaps/OVP_V11-_V12+: D7.1 (A_1), D7.2 (A_2), D8.3 (K), IC4.4 (SN1), IC4.6 (DN2), IC4.7 (GN2), R14.2, R15.1; also elsewhere on the board
GNDD: D8.1 (A_1), D8.2 (A_2), IC4.1 (IC), IC4.5 (SN2,_V-), R16.2; also elsewhere on the board
unnamed: R5.2, R6.1
unnamed: R7.2, R8.1
unnamed: R9.2, R10.1
unnamed: R11.2, R12.1
unnamed: R13.2, R14.1
unnamed: R15.2, R16.1
unnamed: R17.2, R18.1
unnamed: R19.2, R20.1
unnamed: R21.2, R22.1
unnamed: R23.2, R24.1

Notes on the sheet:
Resistance to bypass 3.375mA at 2.7V. The balancing IC will bypass about 3mA at 2.4V and 10mA at 2.7V
CELL BALANCING

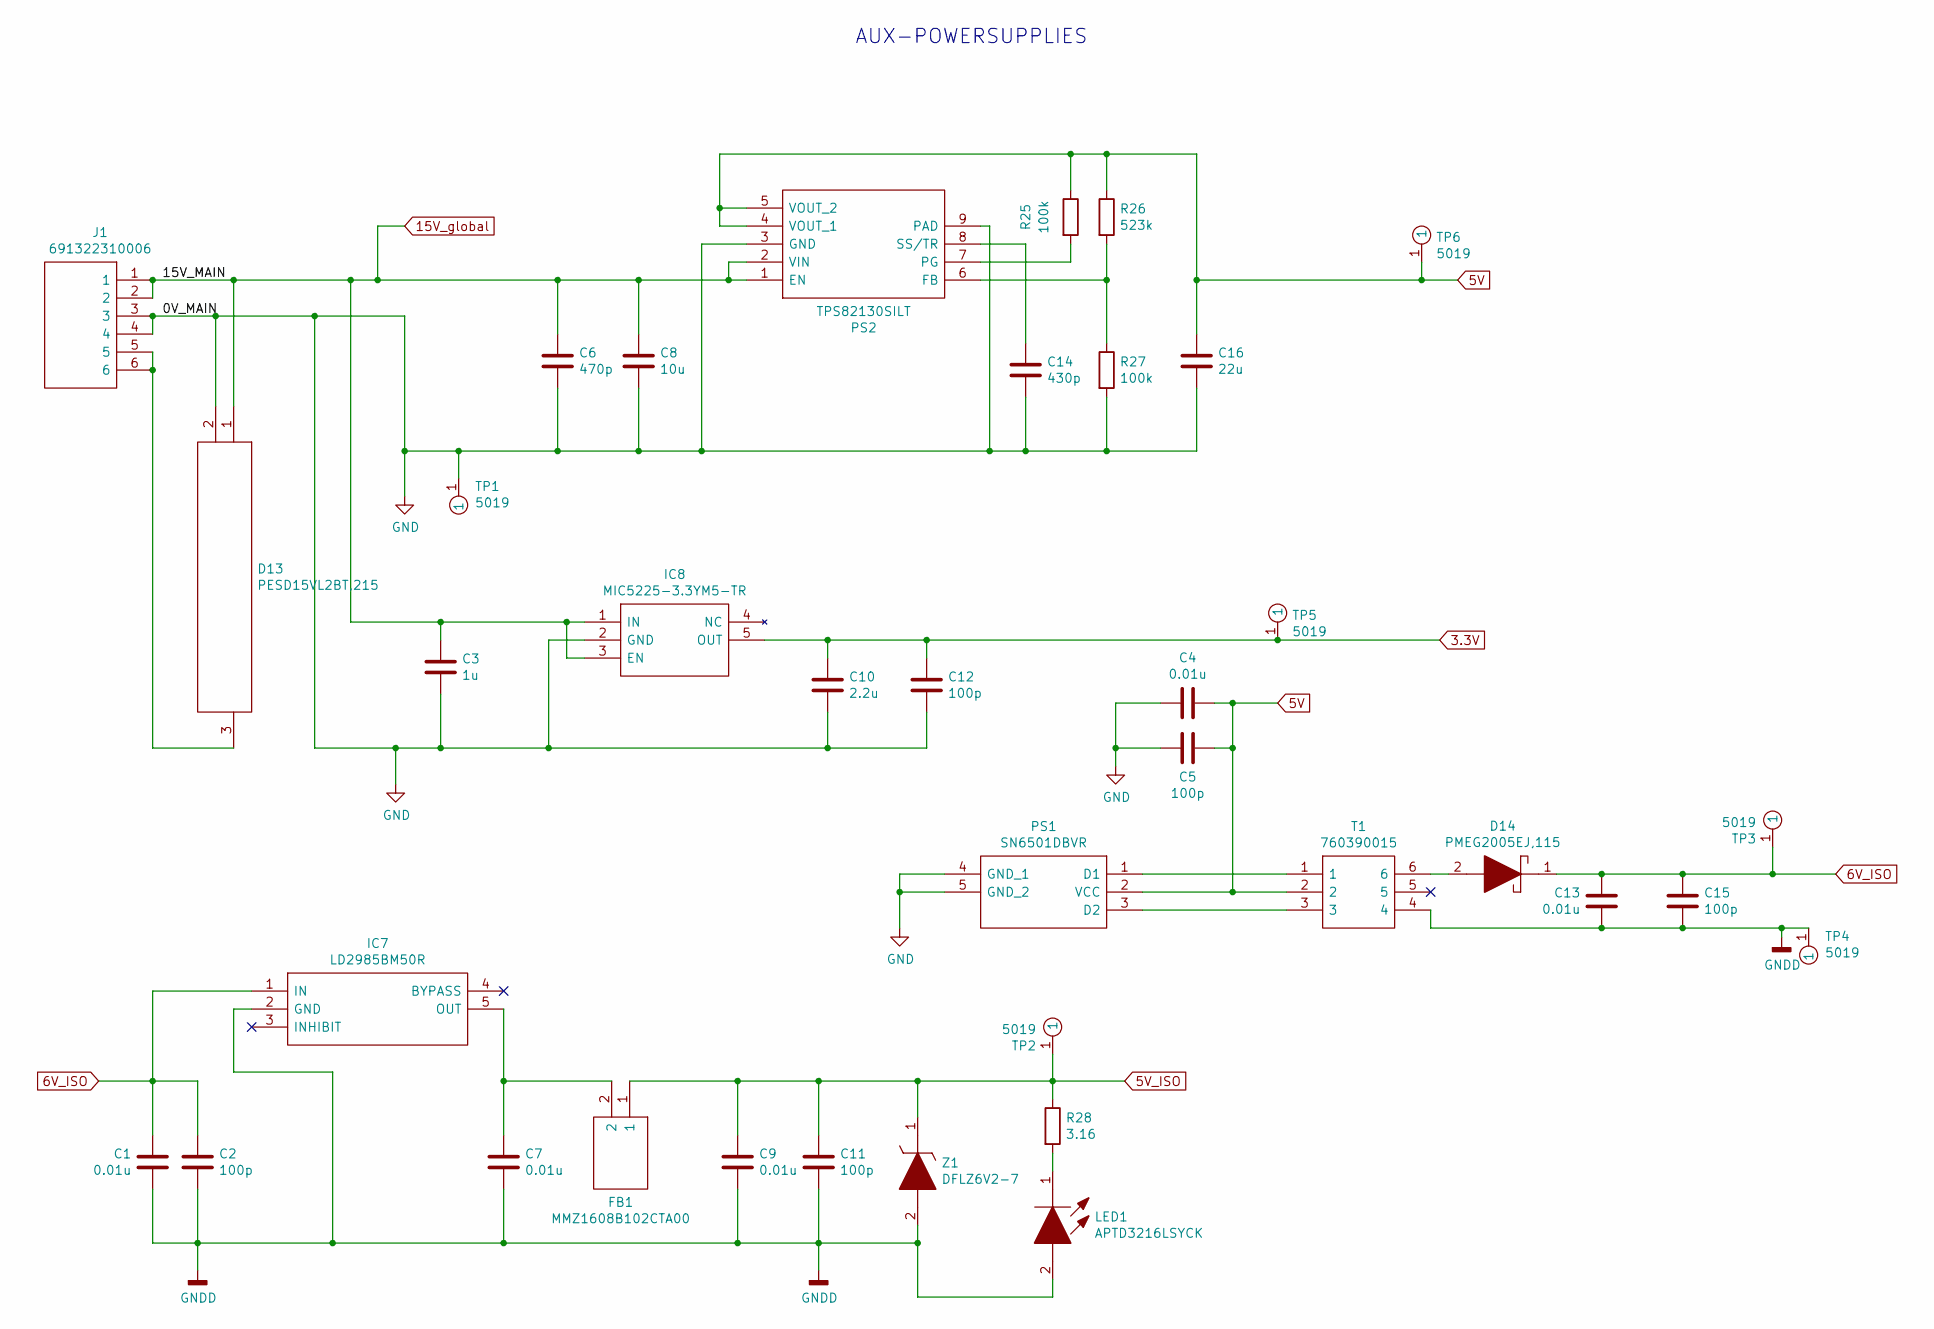
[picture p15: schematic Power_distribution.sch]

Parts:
C1, C4, C7, C9, C13: 0.01u; C_1206_3216Metric_Pad1.33x1.80mm_HandSolder; Mouser Part Number 80-C1206C103F3GECAUT
C2, C5, C11, C12, C15: 100p; C_1206_3216Metric_Pad1.33x1.80mm_HandSolder; Mouser Part Number 581-12063A101FAT2A
C3: 1u; C_1206_3216Metric_Pad1.33x1.80mm_HandSolder; Mouser Part Number 80-C1206C105J3R
C6: 470p; C_1206_3216Metric_Pad1.33x1.80mm_HandSolder; Mouser Part Number 80-C1206C471F5G
C8: 10u; C_1206_3216Metric_Pad1.33x1.80mm_HandSolder; Mouser Part Number 80-C1206C106J3RAUTO
C10: 2.2u; C_1206_3216Metric_Pad1.33x1.80mm_HandSolder; Mouser Part Number 80-C1206C225J4RECLR
C14: 430p; C_1206_3216Metric_Pad1.33x1.80mm_HandSolder; Mouser Part Number 77-VJ12A100V431J
C16: 22u; C_1206_3216Metric_Pad1.33x1.80mm_HandSolder; Mouser Part Number 80-C1206C226K8R7210
D13: PESD15VL2BT,215; SOT95P230X110-3N; Manufacturer_Part_Number PESD15VL2BT,215; Mouser Part Number 771-PESD15VL2BT-T/R
D14: PMEG2005EJ,115; SODFL2512X80N; Manufacturer_Part_Number PMEG2005EJ,115; Mouser Part Number 771-PMEG2005EJ115
FB1: MMZ1608B102CTA00; BEADC1608X95N; Manufacturer_Part_Number MMZ1608B102CTA00; Mouser Part Number 810-MMZ1608B102CTA00
IC7: LD2985BM50R; SOT95P280X145-5N; Manufacturer_Part_Number LD2985BM50R; Mouser Part Number 511-LD2985BM50
IC8: MIC5225-3.3YM5-TR; SOT95P280X145-5N; Manufacturer_Part_Number MIC5225-3.3YM5-TR; Mouser Part Number 998-MIC5225-3.3YM5TR
J1: 691322310006; SHDRRA6W80P0X381_1X6_2405X920X700P; Manufacturer_Part_Number 691322310006; Mouser Part Number 710-691322310006
LED1: APTD3216LSYCK; LEDC3216X200N; Manufacturer_Part_Number APTD3216LSYCK; Mouser Part Number 604-APTD3216LSYCK
PS1: SN6501DBVR; SOT95P280X145-5N; Manufacturer_Part_Number SN6501DBVR; Mouser Part Number 595-SN6501DBVR
PS2: TPS82130SILT; Manufacturer_Part_Number TPS82130SILT; Mouser Part Number 595-TPS82130SILT
R25, R27: 100k; R_1206_3216Metric_Pad1.30x1.75mm_HandSolder; Mouser Part Number 660-RN73R2BTD1003B25
R26: 523k; R_1206_3216Metric_Pad1.30x1.75mm_HandSolder; Mouser Part Number 667-ERA-8AEB5233V
R28: 3.16; R_1206_3216Metric_Pad1.30x1.75mm_HandSolder; Mouser Part Number 71-CRCW12063R16FKEA
T1: 760390015; Manufacturer_Part_Number 760390015; Mouser Part Number 710-760390015
TP1, TP2, TP3, TP4, TP5, TP6: 5019; Manufacturer_Part_Number 5019; Mouser Part Number 534-5019
Z1: DFLZ6V2-7; DFLZ6V87; Manufacturer_Part_Number DFLZ6V2-7; Mouser Part Number 621-DFLZ6V2-7

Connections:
3.3V: C10.1, C12.1, IC8.5 (OUT), TP5.1; also elsewhere on the board
5V: C4.1, C5.1, C16.1, PS1.2 (VCC), PS2.4 (VOUT_1), PS2.5 (VOUT_2), R25.1, R26.1, T1.2, TP6.1; also elsewhere on the board
5V_ISO: C9.2, C11.2, FB1.1, R28.1, TP2.1, Z1.1; also elsewhere on the board
6V_ISO: C1.2, C2.2, C13.2, C15.1, D14.1, IC7.1 (IN), TP3.1; also elsewhere on the board
15V_global: C3.1, C6.1, C8.1, D13.1, IC8.1 (IN), IC8.3 (EN), J1.1, J1.2, PS2.1 (EN), PS2.2 (VIN)
GND: C3.2, C4.2, C5.2, C6.2, C8.2, C10.2, C12.2, C14.2, C16.2, D13.2, IC8.2 (GND), J1.3, J1.4, PS1.4 (GND_1), PS1.5 (GND_2), PS2.3 (GND), PS2.9 (PAD), R27.2, TP1.1; also elsewhere on the board
GNDD: C1.1, C2.1, C7.1, C9.1, C11.1, C13.1, C15.2, IC7.2 (GND), LED1.2, T1.4, TP4.1, Z1.2; also elsewhere on the board
unnamed: C7.2, FB1.2, IC7.5 (OUT)
unnamed: C14.1, PS2.8 (SS/TR)
unnamed: D13.3, J1.5, J1.6
unnamed: D14.2, T1.6
unnamed: LED1.1, R28.2
unnamed: PS1.1 (D1), T1.1
unnamed: PS1.3 (D2), T1.3
unnamed: PS2.6 (FB), R26.2, R27.1
unnamed: PS2.7 (PG), R25.2

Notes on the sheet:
AUX-POWERSUPPLIES

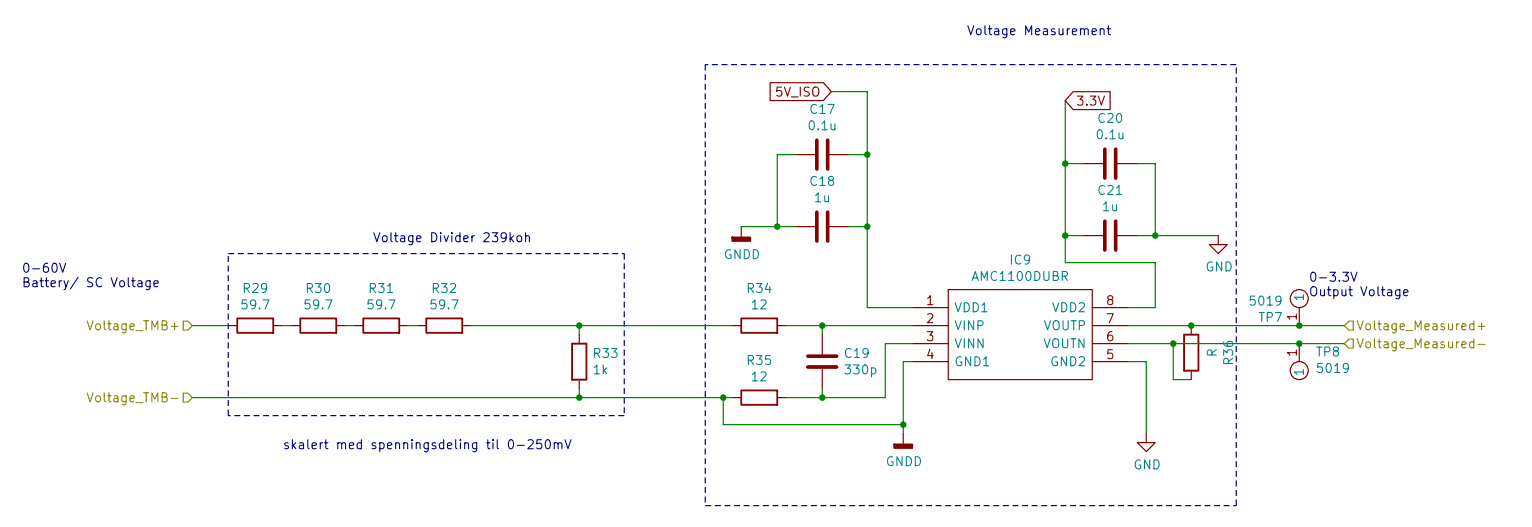
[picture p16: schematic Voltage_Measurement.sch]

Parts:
C17, C20: 0.1u; C_1206_3216Metric_Pad1.33x1.80mm_HandSolder; Mouser Part Number 80-C1206C104F5JACTU
C18, C21: 1u; C_1206_3216Metric_Pad1.33x1.80mm_HandSolder; Mouser Part Number 80-C1206C105J3R
C19: 330p; C_1206_3216Metric_Pad1.33x1.80mm_HandSolder; Mouser Part Number 80-C1206C331F3HACTU
IC9: AMC1100DUBR; SOP254P1040X485-8N; Manufacturer_Part_Number AMC1100DUBR; Mouser Part Number 595-AMC1100DUBR
R29, R30, R31, R32: 59.7; R_1206_3216Metric_Pad1.30x1.75mm_HandSolder; Mouser Part Number 660-RN732BTTD5972B50
R33: 1k; R_1206_3216Metric_Pad1.30x1.75mm_HandSolder; Mouser Part Number 660-RN73H2TD1001B10
R34, R35: 12; R_1206_3216Metric_Pad1.30x1.75mm_HandSolder; Mouser Part Number 603-RT1206BRD0712RL
R36: R; R_1206_3216Metric_Pad1.30x1.75mm_HandSolder; Mouser Part Number 660-RN73H2TD1001B10
TP7, TP8: 5019; Manufacturer_Part_Number 5019; Mouser Part Number 534-5019

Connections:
3.3V: C20.2, C21.2, IC9.8 (VDD2); also elsewhere on the board
5V_ISO: C17.1, C18.1, IC9.1 (VDD1); also elsewhere on the board
/Signaling/ADCINA2_AI: IC9.7 (VOUTP), R36.1, TP7.1; also elsewhere on the board
/Signaling/ADCINA3_AI: IC9.6 (VOUTN), R36.2, TP8.1; also elsewhere on the board
GND: C20.1, C21.1, IC9.5 (GND2); also elsewhere on the board
GNDD: C17.2, C18.2, IC9.4 (GND1), R33.2, R35.1; also elsewhere on the board
unnamed: C19.1, IC9.2 (VINP), R34.2
unnamed: C19.2, IC9.3 (VINN), R35.2
unnamed: R29.2, R30.1
unnamed: R30.2, R31.1
unnamed: R31.2, R32.1
unnamed: R32.2, R33.1, R34.1
OVP_POWER: R29.1; also elsewhere on the board

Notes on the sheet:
0-60V Battery/ SC Voltage
Voltage Divider 239koh
skalert med spenningsdeling til 0-250mV
0-3.3V Output Voltage
Voltage Measurement

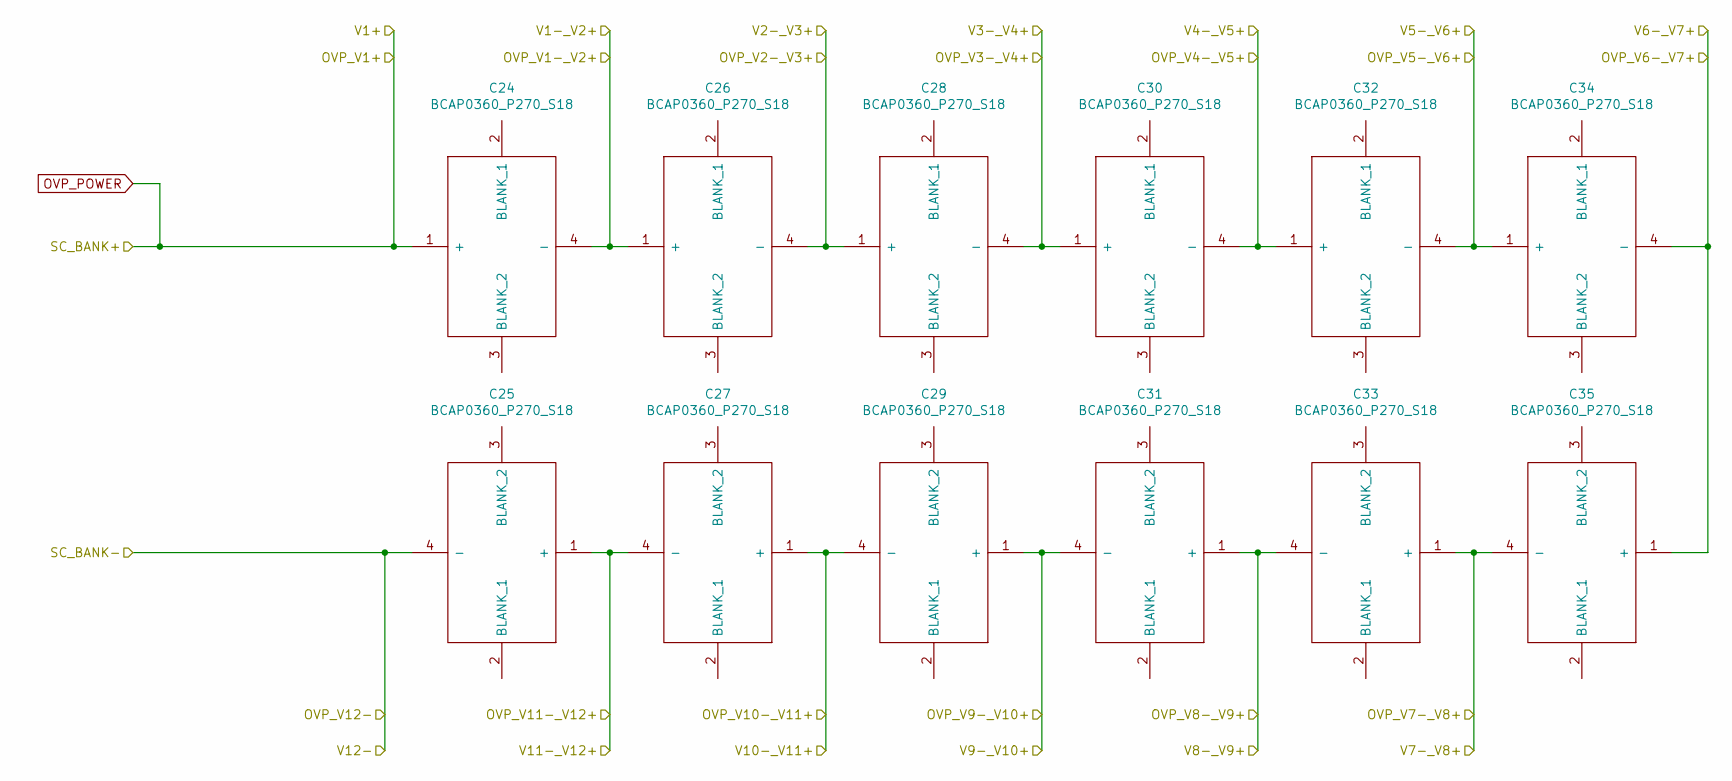
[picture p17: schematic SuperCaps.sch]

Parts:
C24, C25, C26, C27, C28, C29, C30, C31, C32, C33, C34, C35: BCAP0360_P270_S18; BCAP0350P270S18; Manufacturer_Part_Number BCAP0360 P270 S18; Mouser Part Number 723-BCAP0360P270S18

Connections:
/Supercaps/OVP_V1-_V2+: C24.4 (-), C26.1 (+); also elsewhere on the board
/Supercaps/OVP_V2-_V3+: C26.4 (-), C28.1 (+); also elsewhere on the board
/Supercaps/OVP_V3-_V4+: C28.4 (-), C30.1 (+); also elsewhere on the board
/Supercaps/OVP_V4-_V5+: C30.4 (-), C32.1 (+); also elsewhere on the board
/Supercaps/OVP_V5-_V6+: C32.4 (-), C34.1 (+); also elsewhere on the board
/Supercaps/OVP_V6-_V7+: C34.4 (-), C35.1 (+); also elsewhere on the board
/Supercaps/OVP_V7-_V8+: C33.1 (+), C35.4 (-); also elsewhere on the board
/Supercaps/OVP_V8-_V9+: C31.1 (+), C33.4 (-); also elsewhere on the board
/Supercaps/OVP_V9-_V10+: C29.1 (+), C31.4 (-); also elsewhere on the board
/Supercaps/OVP_V10-_V11+: C27.1 (+), C29.4 (-); also elsewhere on the board
/Supercaps/OVP_V11-_V12+: C25.1 (+), C27.4 (-); also elsewhere on the board
GNDD: C25.4 (-); also elsewhere on the board
OVP_POWER: C24.1 (+); also elsewhere on the board

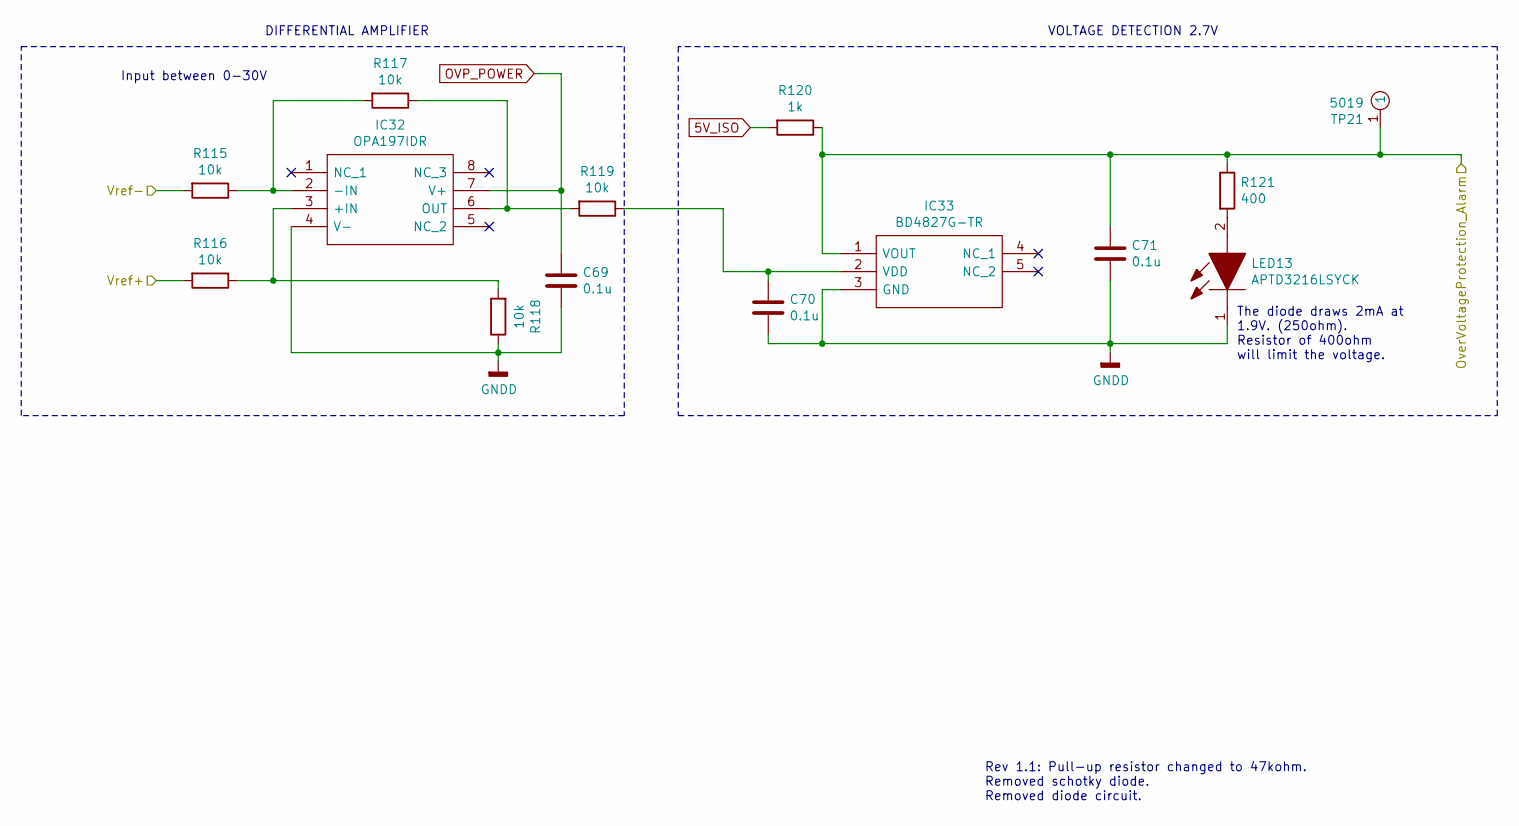
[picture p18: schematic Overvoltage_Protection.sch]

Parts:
C66, C67, C68: 0.1u; C_1206_3216Metric_Pad1.33x1.80mm_HandSolder; Mouser Part Number 80-C1206C104F5JACTU
IC10: OPA197IDR; SOIC127P600X175-8N; Manufacturer_Part_Number OPA197IDR; Mouser Part Number 595-OPA197IDR
IC31: BD4827G-TR; SOT95P280X125-5N; Manufacturer_Part_Number BD4827G-TR; Mouser Part Number 755-BD4827G-TR
LED12: APTD3216LSYCK; LEDC3216X200N; Manufacturer_Part_Number APTD3216LSYCK; Mouser Part Number 604-APTD3216LSYCK
R38, R39, R40, R41, R42: 10k; R_1206_3216Metric_Pad1.30x1.75mm_HandSolder; Mouser Part Number 660-RN73H2BTD1002B10
R43: 1k; R_1206_3216Metric_Pad1.30x1.75mm_HandSolder; Mouser Part Number 660-RN73H2TD1001B10
R44: 400; R_1206_3216Metric_Pad1.30x1.75mm_HandSolder; Mouser Part Number 660-RN732BTTD4000B25
TP10: 5019; Manufacturer_Part_Number 5019; Mouser Part Number 534-5019

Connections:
5V_ISO: R43.2; also elsewhere on the board
/Supercaps/OVP_V11-_V12+: R39.2; also elsewhere on the board
GNDD: C66.2, C67.2, C68.2, IC10.4 (V-), IC31.3 (GND), LED12.1, R38.2, R41.1; also elsewhere on the board
unnamed: IC10.2 (-IN), R38.1, R40.2
unnamed: IC10.3 (+IN), R39.1, R41.2
unnamed: IC10.6 (OUT), R40.1, R42.2
OVP_POWER: C66.1, IC10.7 (V+); also elsewhere on the board

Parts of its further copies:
C36, C37, C38, C39, C40, C41, C42, C43, C44, C45, C46, C47, C48, C49, C50, C51, C52, C53, C54, C55, C56, C57, C58, C59, C60, C61, C62, C63, C64, C65, C69, C70, C71: 0.1u; C_1206_3216Metric_Pad1.33x1.80mm_HandSolder; Mouser Part Number 80-C1206C104F5JACTU
IC11, IC13, IC15, IC17, IC19, IC21, IC23, IC25, IC27, IC29, IC33: BD4827G-TR; SOT95P280X125-5N; Manufacturer_Part_Number BD4827G-TR; Mouser Part Number 755-BD4827G-TR
IC12, IC14, IC16, IC18, IC20, IC22, IC24, IC26, IC28, IC30, IC32: OPA197IDR; SOIC127P600X175-8N; Manufacturer_Part_Number OPA197IDR; Mouser Part Number 595-OPA197IDR
LED2, LED3, LED4, LED5, LED6, LED7, LED8, LED9, LED10, LED11, LED13: APTD3216LSYCK; LEDC3216X200N; Manufacturer_Part_Number APTD3216LSYCK; Mouser Part Number 604-APTD3216LSYCK
R45, R46, R47, R48, R49, R52, R53, R54, R55, R56, R59, R60, R61, R62, R63, R66, R67, R68, R69, R70, R73, R74, R75, R76, R77, R80, R81, R82, R83, R84, R87, R88, R89, R90, R91, R94, R95, R96, R97, R98, R101, R102, R103, R104, R105, R108, R109, R110, R111, R112, R115, R116, R117, R118, R119: 10k; R_1206_3216Metric_Pad1.30x1.75mm_HandSolder; Mouser Part Number 660-RN73H2BTD1002B10
R50, R57, R64, R71, R78, R85, R92, R99, R106, R113, R120: 1k; R_1206_3216Metric_Pad1.30x1.75mm_HandSolder; Mouser Part Number 660-RN73H2TD1001B10
R51, R58, R65, R72, R79, R86, R93, R100, R107, R114, R121: 400; R_1206_3216Metric_Pad1.30x1.75mm_HandSolder; Mouser Part Number 660-RN732BTTD4000B25
TP11, TP12, TP13, TP14, TP15, TP16, TP17, TP18, TP19, TP20, TP21: 5019; Manufacturer_Part_Number 5019; Mouser Part Number 534-5019

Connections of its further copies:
5V_ISO: R50.2, R57.2, R64.2, R71.2, R78.2, R85.2, R92.2, R99.2, R106.2, R113.2, R120.2; also elsewhere on the board
/Isolation-IC/IN_PORT_2: C59.1, IC25.1 (VOUT), R92.1, R93.1, TP17.1; also elsewhere on the board
/Isolation-IC/IN_PORT_3: C71.1, IC33.1 (VOUT), R120.1, R121.1, TP21.1; also elsewhere on the board
/Isolation-IC/IN_PORT_4: C56.1, IC23.1 (VOUT), R85.1, R86.1, TP16.1; also elsewhere on the board
/Isolation-IC/IN_PORT_5: C65.1, IC29.1 (VOUT), R106.1, R107.1, TP19.1; also elsewhere on the board
/Isolation-IC/IN_PORT_6: C53.1, IC21.1 (VOUT), R78.1, R79.1, TP15.1; also elsewhere on the board
/Isolation-IC/IN_PORT_7: C62.1, IC27.1 (VOUT), R99.1, R100.1, TP18.1; also elsewhere on the board
/Isolation-IC/IN_PORT_8: C50.1, IC19.1 (VOUT), R71.1, R72.1, TP14.1; also elsewhere on the board
/Isolation-IC/IN_PORT_9: C47.1, IC17.1 (VOUT), R64.1, R65.1, TP13.1; also elsewhere on the board
/Isolation-IC/IN_PORT_10: C44.1, IC15.1 (VOUT), R57.1, R58.1, TP12.1; also elsewhere on the board
/Isolation-IC/IN_PORT_11: C41.1, IC13.1 (VOUT), R50.1, R51.1, TP11.1; also elsewhere on the board
/Supercaps/OVP_V1-_V2+: R88.2, R108.2; also elsewhere on the board
/Supercaps/OVP_V2-_V3+: R87.2, R116.2; also elsewhere on the board
/Supercaps/OVP_V3-_V4+: R81.2, R115.2; also elsewhere on the board
/Supercaps/OVP_V4-_V5+: R80.2, R102.2; also elsewhere on the board
/Supercaps/OVP_V5-_V6+: R74.2, R101.2; also elsewhere on the board
/Supercaps/OVP_V6-_V7+: R73.2, R95.2; also elsewhere on the board
/Supercaps/OVP_V7-_V8+: R67.2, R94.2; also elsewhere on the board
/Supercaps/OVP_V8-_V9+: R60.2, R66.2; also elsewhere on the board
/Supercaps/OVP_V9-_V10+: R53.2, R59.2; also elsewhere on the board
/Supercaps/OVP_V10-_V11+: R46.2, R52.2; also elsewhere on the board
/Supercaps/OVP_V11-_V12+: R45.2; also elsewhere on the board
GNDD: C36.2, C37.2, C38.2, C39.2, C40.2, C41.2, C42.2, C43.2, C44.2, C45.2, C46.2, C47.2, C48.2, C49.2, C50.2, C51.2, C52.2, C53.2, C54.2, C55.2, C56.2, C57.2, C58.2, C59.2, C60.2, C61.2, C62.2, C63.2, C64.2, C65.2, C69.2, C70.2, C71.2, IC11.3 (GND), IC12.4 (V-), IC13.3 (GND), IC14.4 (V-), IC15.3 (GND), IC16.4 (V-), IC17.3 (GND), IC18.4 (V-), IC19.3 (GND), IC20.4 (V-), IC21.3 (GND), IC22.4 (V-), IC23.3 (GND), IC24.4 (V-), IC25.3 (GND), IC26.4 (V-), IC27.3 (GND), IC28.4 (V-), IC29.3 (GND), IC30.4 (V-), IC32.4 (V-), IC33.3 (GND), LED2.1, LED3.1, LED4.1, LED5.1, LED6.1, LED7.1, LED8.1, LED9.1, LED10.1, LED11.1, LED13.1, R48.1, R55.1, R62.1, R69.1, R76.1, R83.1, R90.1, R97.1, R104.1, R111.1, R118.1; also elsewhere on the board
unnamed: C40.1, IC13.2 (VDD), R49.1
unnamed: C43.1, IC15.2 (VDD), R56.1
unnamed: C46.1, IC17.2 (VDD), R63.1
unnamed: C49.1, IC19.2 (VDD), R70.1
unnamed: C52.1, IC21.2 (VDD), R77.1
unnamed: C55.1, IC23.2 (VDD), R84.1
unnamed: C58.1, IC25.2 (VDD), R91.1
unnamed: C61.1, IC27.2 (VDD), R98.1
unnamed: C64.1, IC29.2 (VDD), R105.1
unnamed: C70.1, IC33.2 (VDD), R119.1
unnamed: IC12.2 (-IN), R45.1, R47.2
unnamed: IC12.3 (+IN), R46.1, R48.2
unnamed: IC12.6 (OUT), R47.1, R49.2
unnamed: IC14.2 (-IN), R52.1, R54.2
unnamed: IC14.3 (+IN), R53.1, R55.2
unnamed: IC14.6 (OUT), R54.1, R56.2
unnamed: IC16.2 (-IN), R59.1, R61.2
unnamed: IC16.3 (+IN), R60.1, R62.2
unnamed: IC16.6 (OUT), R61.1, R63.2
unnamed: IC18.2 (-IN), R66.1, R68.2
unnamed: IC18.3 (+IN), R67.1, R69.2
unnamed: IC18.6 (OUT), R68.1, R70.2
unnamed: IC20.2 (-IN), R73.1, R75.2
unnamed: IC20.3 (+IN), R74.1, R76.2
unnamed: IC20.6 (OUT), R75.1, R77.2
unnamed: IC22.2 (-IN), R80.1, R82.2
unnamed: IC22.3 (+IN), R81.1, R83.2
unnamed: IC22.6 (OUT), R82.1, R84.2
unnamed: IC24.2 (-IN), R87.1, R89.2
unnamed: IC24.3 (+IN), R88.1, R90.2
unnamed: IC24.6 (OUT), R89.1, R91.2
unnamed: IC26.2 (-IN), R94.1, R96.2
unnamed: IC26.3 (+IN), R95.1, R97.2
unnamed: IC26.6 (OUT), R96.1, R98.2
unnamed: IC28.2 (-IN), R101.1, R103.2
unnamed: IC28.3 (+IN), R102.1, R104.2
unnamed: IC28.6 (OUT), R103.1, R105.2
unnamed: IC30.2 (-IN), R108.1, R110.2
unnamed: IC30.3 (+IN), R109.1, R111.2
unnamed: IC30.6 (OUT), R110.1, R112.2
unnamed: IC32.2 (-IN), R115.1, R117.2
unnamed: IC32.3 (+IN), R116.1, R118.2
unnamed: IC32.6 (OUT), R117.1, R119.2
unnamed: LED3.2, R51.2
unnamed: LED4.2, R58.2
unnamed: LED5.2, R65.2
unnamed: LED6.2, R72.2
unnamed: LED7.2, R79.2
unnamed: LED8.2, R86.2
unnamed: LED9.2, R93.2
unnamed: LED10.2, R100.2
unnamed: LED11.2, R107.2
unnamed: LED13.2, R121.2
OVP_POWER: C36.1, C39.1, C42.1, C45.1, C48.1, C51.1, C54.1, C57.1, C60.1, C63.1, C69.1, IC12.7 (V+), IC14.7 (V+), IC16.7 (V+), IC18.7 (V+), IC20.7 (V+), IC22.7 (V+), IC24.7 (V+), IC26.7 (V+), IC28.7 (V+), IC30.7 (V+), IC32.7 (V+), R109.2; also elsewhere on the board

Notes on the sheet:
Input between 0-30V
The diode draws 2mA at 1.9V. (250ohm). Resistor of 400ohm will limit the voltage.
DIFFERENTIAL AMPLIFIER
VOLTAGE DETECTION 2.7V
Rev 1.1: Pull-up resistor changed to 47kohm. Removed schotky diode. Removed diode circuit.

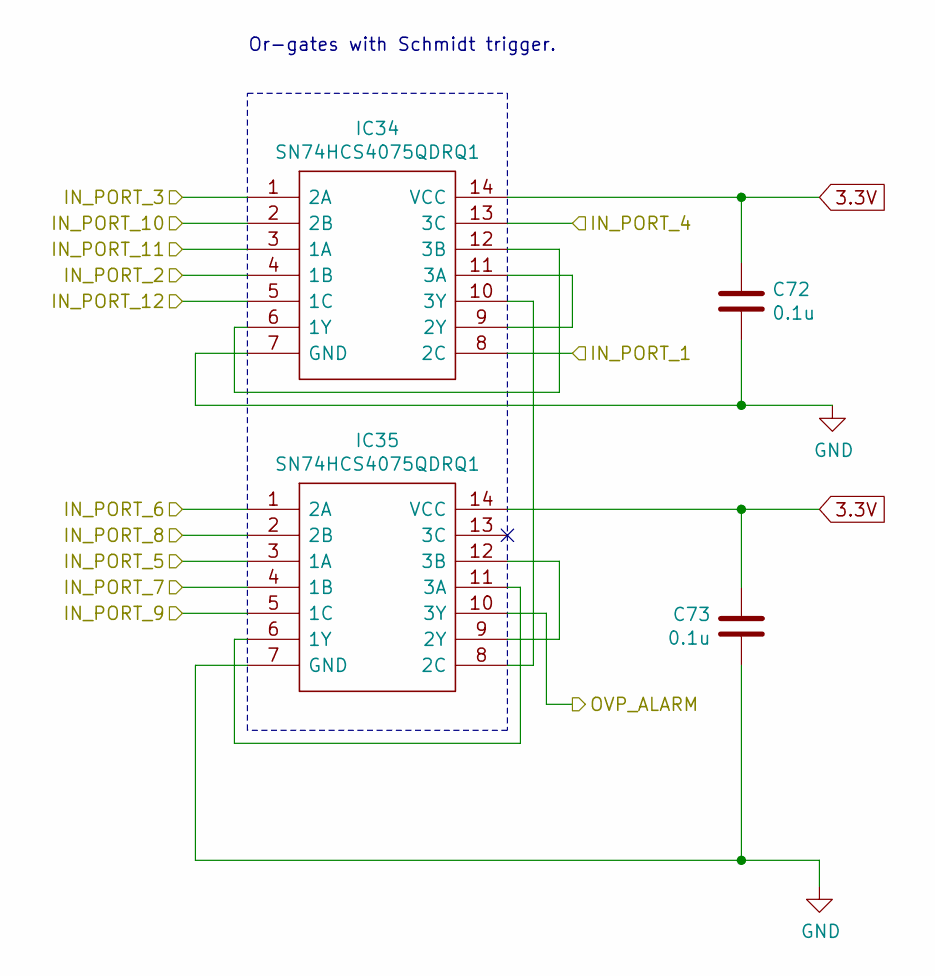
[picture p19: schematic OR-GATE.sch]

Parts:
C72, C73: 0.1u; C_1206_3216Metric_Pad1.33x1.80mm_HandSolder; Mouser Part Number 80-C1206C104F5JACTU
IC34, IC35: SN74HCS4075QDRQ1; SOIC127P600X175-14N; Manufacturer_Part_Number SN74HCS4075QDRQ1; Mouser Part Number 595-SN74HCS4075QDRQ1

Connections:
3.3V: C72.1, C73.1, IC34.14 (VCC), IC35.14 (VCC); also elsewhere on the board
/OR-GATE/IN_PORT_1: IC34.8 (2C); also elsewhere on the board
/OR-GATE/IN_PORT_2: IC34.4 (1B); also elsewhere on the board
/OR-GATE/IN_PORT_3: IC34.1 (2A); also elsewhere on the board
/OR-GATE/IN_PORT_4: IC34.13 (3C); also elsewhere on the board
/OR-GATE/IN_PORT_5: IC35.3 (1A); also elsewhere on the board
/OR-GATE/IN_PORT_6: IC35.1 (2A); also elsewhere on the board
/OR-GATE/IN_PORT_7: IC35.4 (1B); also elsewhere on the board
/OR-GATE/IN_PORT_8: IC35.2 (2B); also elsewhere on the board
/OR-GATE/IN_PORT_9: IC35.5 (1C); also elsewhere on the board
/OR-GATE/IN_PORT_10: IC34.2 (2B); also elsewhere on the board
/OR-GATE/IN_PORT_11: IC34.3 (1A); also elsewhere on the board
/OR-GATE/IN_PORT_12: IC34.5 (1C); also elsewhere on the board
/Signaling/GPIO_P52: IC35.10 (3Y); also elsewhere on the board
GND: C72.2, C73.2, IC34.7 (GND), IC35.7 (GND); also elsewhere on the board
unnamed: IC34.10 (3Y), IC35.8 (2C)
unnamed: IC34.9 (2Y), IC34.11 (3A)
unnamed: IC34.6 (1Y), IC34.12 (3B)
unnamed: IC35.6 (1Y), IC35.11 (3A)
unnamed: IC35.9 (2Y), IC35.12 (3B)

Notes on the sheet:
Or-gates with Schmidt trigger.

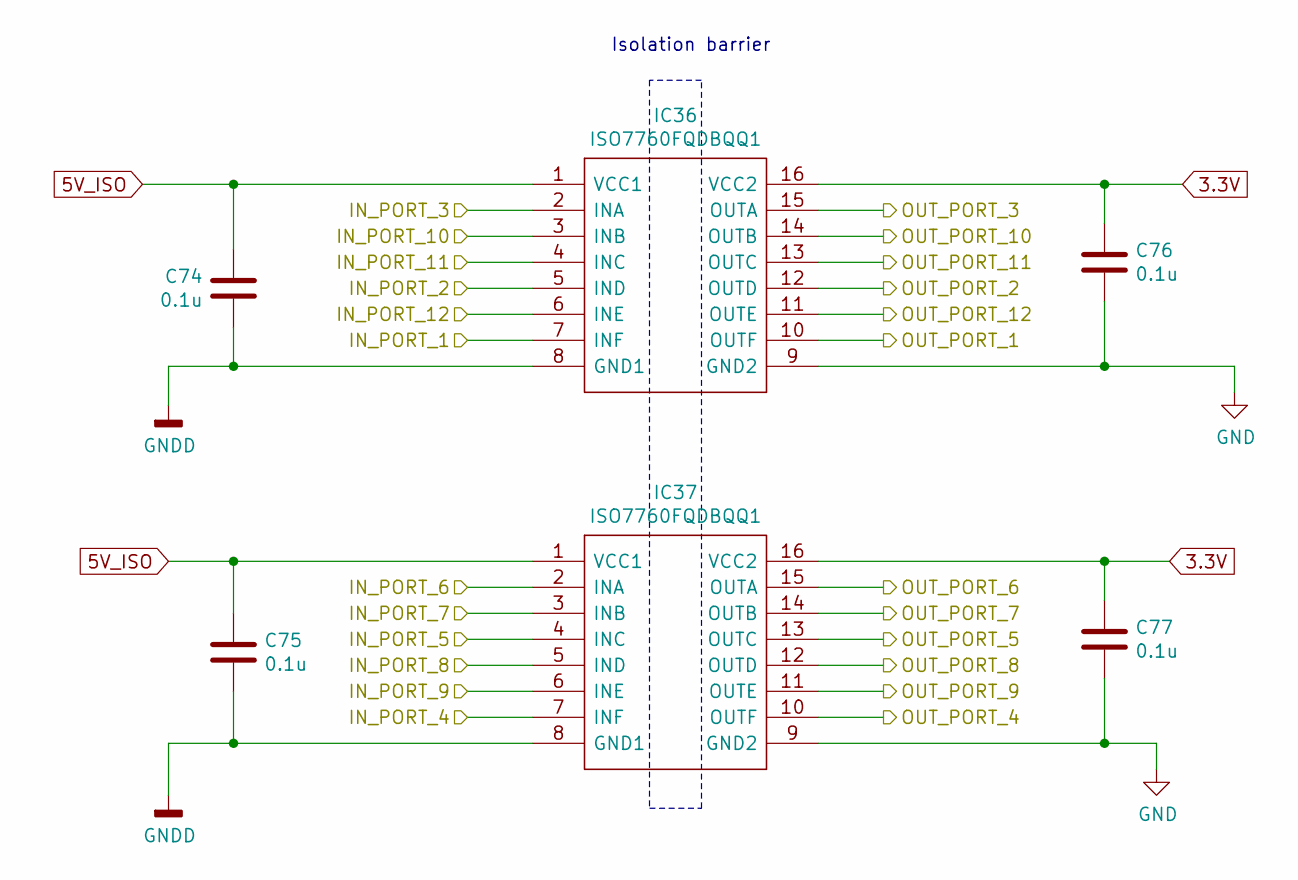
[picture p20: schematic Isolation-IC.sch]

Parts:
C74, C75, C76, C77: 0.1u; C_1206_3216Metric_Pad1.33x1.80mm_HandSolder; Mouser Part Number 80-C1206C104F5JACTU
IC36, IC37: ISO7760FQDBQQ1; SOP64P600X175-16N; Manufacturer_Part_Number ISO7760FQDBQQ1; Mouser Part Number 595-ISO7760FQDBQQ1

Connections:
3.3V: C76.1, C77.1, IC36.16 (VCC2), IC37.16 (VCC2); also elsewhere on the board
5V_ISO: C74.1, C75.1, IC36.1 (VCC1), IC37.1 (VCC1); also elsewhere on the board
/Isolation-IC/IN_PORT_2: IC36.5 (IND); also elsewhere on the board
/Isolation-IC/IN_PORT_3: IC36.2 (INA); also elsewhere on the board
/Isolation-IC/IN_PORT_4: IC37.7 (INF); also elsewhere on the board
/Isolation-IC/IN_PORT_5: IC37.4 (INC); also elsewhere on the board
/Isolation-IC/IN_PORT_6: IC37.2 (INA); also elsewhere on the board
/Isolation-IC/IN_PORT_7: IC37.3 (INB); also elsewhere on the board
/Isolation-IC/IN_PORT_8: IC37.5 (IND); also elsewhere on the board
/Isolation-IC/IN_PORT_9: IC37.6 (INE); also elsewhere on the board
/Isolation-IC/IN_PORT_10: IC36.3 (INB); also elsewhere on the board
/Isolation-IC/IN_PORT_11: IC36.4 (INC); also elsewhere on the board
/OR-GATE/IN_PORT_1: IC36.10 (OUTF); also elsewhere on the board
/OR-GATE/IN_PORT_2: IC36.12 (OUTD); also elsewhere on the board
/OR-GATE/IN_PORT_3: IC36.15 (OUTA); also elsewhere on the board
/OR-GATE/IN_PORT_4: IC37.10 (OUTF); also elsewhere on the board
/OR-GATE/IN_PORT_5: IC37.13 (OUTC); also elsewhere on the board
/OR-GATE/IN_PORT_6: IC37.15 (OUTA); also elsewhere on the board
/OR-GATE/IN_PORT_7: IC37.12 (OUTD); also elsewhere on the board
/OR-GATE/IN_PORT_8: IC37.14 (OUTB); also elsewhere on the board
/OR-GATE/IN_PORT_9: IC37.11 (OUTE); also elsewhere on the board
/OR-GATE/IN_PORT_10: IC36.14 (OUTB); also elsewhere on the board
/OR-GATE/IN_PORT_11: IC36.13 (OUTC); also elsewhere on the board
/OR-GATE/IN_PORT_12: IC36.11 (OUTE); also elsewhere on the board
GND: C76.2, C77.2, IC36.9 (GND2), IC37.9 (GND2); also elsewhere on the board
GNDD: C74.2, C75.2, IC36.8 (GND1), IC37.8 (GND1); also elsewhere on the board

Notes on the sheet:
Isolation barrier

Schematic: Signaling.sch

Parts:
J2: 15-47-7512; 15477512; Manufacturer_Part_Number 15-47-7512; Mouser Part Number 538-15-47-7512

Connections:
3.3V: J2.B6; also elsewhere on the board
5V: J2.A6; also elsewhere on the board
/Precharge/Charge_Active: J2.B5; also elsewhere on the board
/Signaling/ADCINA0_AI: J2.B3; also elsewhere on the board
/Signaling/ADCINA2_AI: J2.B2; also elsewhere on the board
/Signaling/ADCINA3_AI: J2.A1; also elsewhere on the board
/Signaling/GPIO_P22: J2.A5; also elsewhere on the board
/Signaling/GPIO_P52: J2.A4; also elsewhere on the board
/Signaling/GPIO_P97: J2.B4; also elsewhere on the board
GND: J2.A2, J2.A3, J2.B1; also elsewhere on the board

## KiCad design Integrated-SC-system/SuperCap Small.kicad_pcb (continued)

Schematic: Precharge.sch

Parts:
C78, C79, C80, C81, C82: 0.1u; C_1206_3216Metric_Pad1.33x1.80mm_HandSolder; Mouser Part Number 80-C1206C104F5JACTU
C83, C84: 1u; C_1206_3216Metric_Pad1.33x1.80mm_HandSolder; Mouser Part Number 80-C1206C105J3R
D15, D16, D17: RS07D-HM3-08; SODFL3718X108N; Manufacturer_Part_Number RS07D-HM3-08; Mouser Part Number 78-RS07D-HM3-08
IC38, IC39: UCC21220AD; SOIC127P600X175-16N; Manufacturer_Part_Number UCC21220AD; Mouser Part Number 595-UCC21220AD
J3, J4: 1717017; Manufacturer_Part_Number 1717017; Mouser Part Number 651-1717017
Q1, Q2, Q3: BSZ024N04LS6ATMA1; Manufacturer_Part_Number BSZ024N04LS6ATMA1; Mouser Part Number 726-BSZ024N04LS6ATMA
R122, R123, R124: rc; R_1206_3216Metric_Pad1.30x1.75mm_HandSolder; Mouser Part Number 71-RCS120651R0FKEA
R125, R126, R127, R128, R129, R130: R; R_1206_3216Metric_Pad1.30x1.75mm_HandSolder; Mouser Part Number 660-RN73H2TD1001B10
R131: 30; TO-263-2_TabPin1; Manufacturer_Part_Number AP750 25R F; Mouser Part Number 284-AP75025RF
TP22, TP23, TP24, TP25, TP26, TP27: 5019; Manufacturer_Part_Number 5019; Mouser Part Number 534-5019

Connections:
3.3V: C81.1, C82.1, IC38.3 (VCCI_1), IC39.3 (VCCI_1), IC39.8 (VCCI_2); also elsewhere on the board
6V_ISO: C83.1, C84.1, IC38.16 (VDDA), IC39.11 (VDDB), IC39.16 (VDDA); also elsewhere on the board
/Precharge/CHARGE_INN: J3.7, J3.8, J3.9, Q1.1 (S_1), Q1.2 (S_2), Q1.3 (S_3), Q1.9 (S_4), R131.1
/Precharge/Charge_Active: R123.1, TP23.1; also elsewhere on the board
/Precharge/LOAD_INN: J3.1, J3.2, J3.3, Q3.5 (D_1), Q3.6 (D_2), Q3.7 (D_3), Q3.8 (D_4), Q3.10 (D_5)
/Sheet6014032E/Current_TBM+: J4.1, J4.2, J4.3, J4.4, J4.5, J4.6, J4.7, J4.8, J4.9; also elsewhere on the board
/Signaling/GPIO_P22: R124.1, TP24.1; also elsewhere on the board
/Signaling/GPIO_P97: R122.1, TP22.1; also elsewhere on the board
Charge_Gate: D16.2, Q1.4 (G), R129.2, TP26.1
GND: C78.2, C79.2, C80.2, C81.2, C82.2, IC38.4 (GND), IC39.4 (GND); also elsewhere on the board
GNDD: C83.2, C84.2, IC38.14 (VSSA), IC39.9 (VSSB), IC39.14 (VSSA), Q1.5 (D_1), Q1.6 (D_2), Q1.7 (D_3), Q1.8 (D_4), Q1.10 (D_5), Q2.5 (D_1), Q2.6 (D_2), Q2.7 (D_3), Q2.8 (D_4), Q2.10 (D_5), Q3.1 (S_1), Q3.2 (S_2), Q3.3 (S_3), Q3.9 (S_4); also elsewhere on the board
Load_Gate: D15.2, Q3.4 (G), R126.2, TP25.1
unnamed: C78.1, IC39.1 (INA), R122.2
unnamed: C79.1, IC39.2 (INB), R123.2
unnamed: C80.1, IC38.1 (INA), R124.2
unnamed: D15.1, R125.2
unnamed: D16.1, R127.2
unnamed: D17.1, R128.2
unnamed: IC38.15 (OUTA), R125.1, R126.1
unnamed: IC39.10 (OUTB), R128.1, R130.1
unnamed: IC39.15 (OUTA), R127.1, R129.1
unnamed: Q2.1 (S_1), Q2.2 (S_2), Q2.3 (S_3), Q2.9 (S_4), R131.2
Precharge_Gate: D17.2, Q2.4 (G), R130.2, TP27.1

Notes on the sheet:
Leakage from Supercaps and balancing is about 42mA. This will be the continuous maintenance current. Balancing resistor = 1.5mohm per 2 supercaps. Leakage current supercaps = 0.75mA per supercap Balancing IC bypasses roughly 2mA per supercap at 2.7V Resister should be 30V/42mA = 714 ohm
Isolation
6V reference, Min for VDD
Charge is set high after precharge by kontroller. RC-filter
Load signal triggered by kontroller. RC-filter
POSITIVE CONNECTOR FOR CHARGE AND LOAD
NEGATIVE CONNECTOR FOR CHARGE AND LOAD
Rev. 1.1 Fixed error with charge and pre_charge signal.
Rev. 1.1 Fixed error with charge and pre_charge signal.
Rev. 1.0 Finished design and ordered.
Sets the precharge active. Is reset by microkontroller. RC-filter
Mosfets placed after Load and SC bank to achieve V_g >=V_s + V_th. The gate to source voltage must be greater then the threshold-voltage.
Precharge resistor
MAIN POWERSUPPLY AND LOAD

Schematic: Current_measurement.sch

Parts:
C22: 0.1u; C_1206_3216Metric_Pad1.33x1.80mm_HandSolder; Mouser Part Number 80-C1206C104F5JACTU
C23: 1u; C_1206_3216Metric_Pad1.33x1.80mm_HandSolder; Mouser Part Number 80-C1206C105J3R
R37: R; R_1206_3216Metric_Pad1.30x1.75mm_HandSolder; Mouser Part Number 660-RN73H2TD1001B10
TP9: 5019; Manufacturer_Part_Number 5019; Mouser Part Number 534-5019
U1: ACS758LCB-050B-PFF-T; Allegro_CB_PFF

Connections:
3.3V: C22.1, U1.1 (VCC); also elsewhere on the board
/Sheet6014032E/Current_TBM+: U1.4 (IP+); also elsewhere on the board
/Signaling/ADCINA0_AI: C23.1, R37.2, TP9.1; also elsewhere on the board
GND: C22.2, C23.2, U1.2 (GND); also elsewhere on the board
unnamed: R37.1, U1.3 (VIOUT)
OVP_POWER: U1.5 (IP-); also elsewhere on the board

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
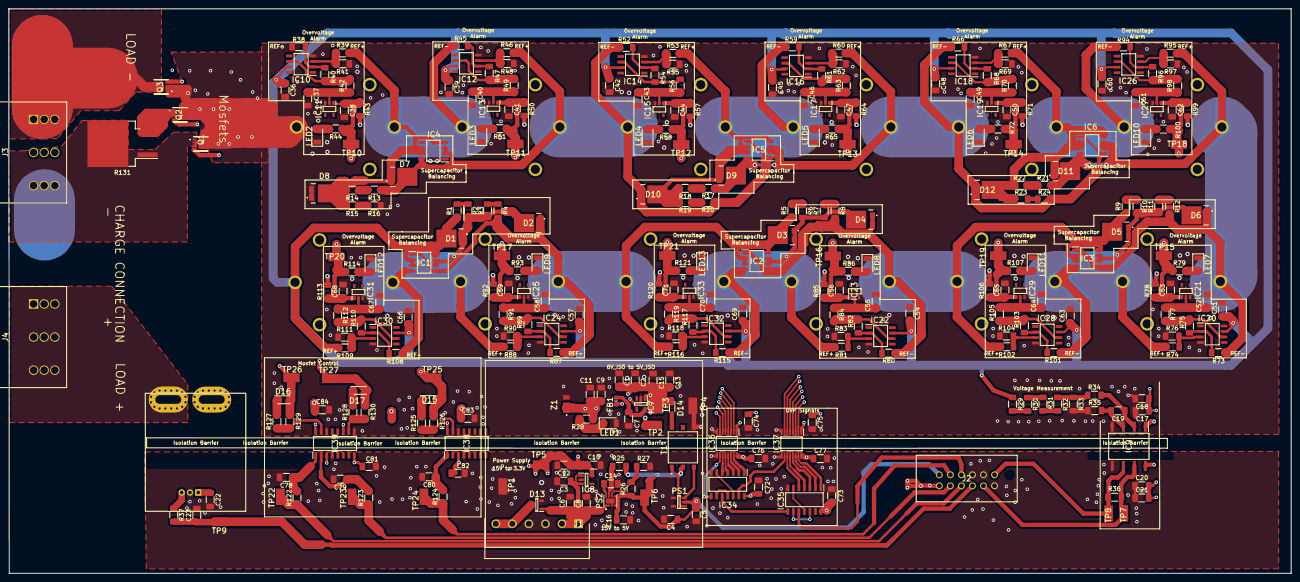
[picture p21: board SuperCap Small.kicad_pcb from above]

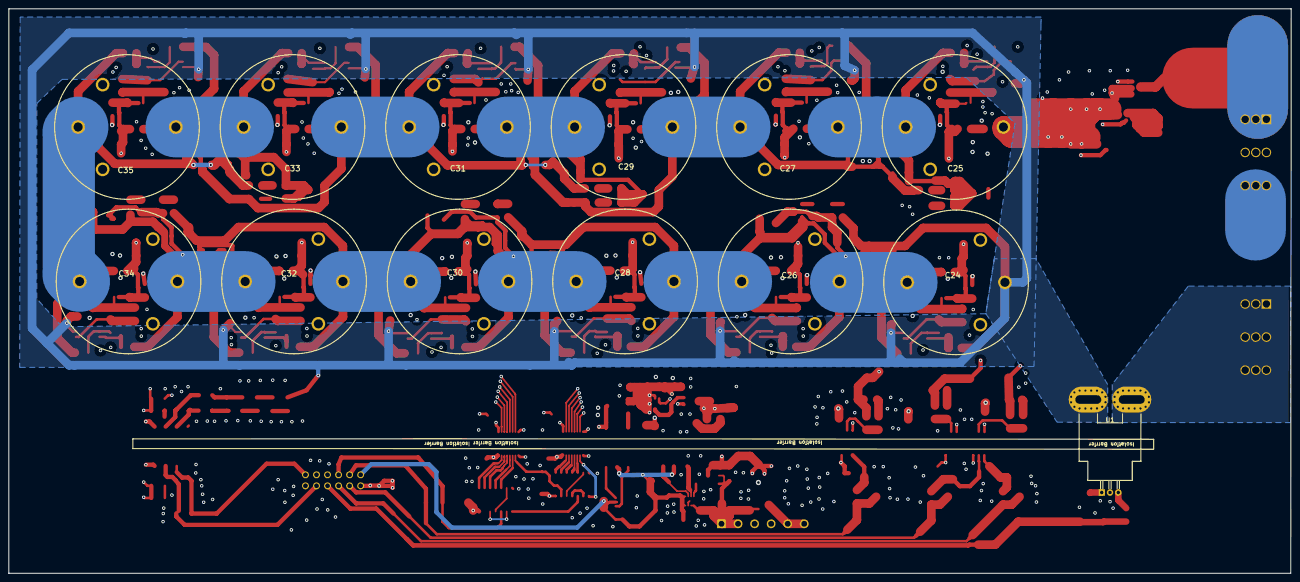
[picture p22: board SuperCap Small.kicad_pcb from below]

Board: 4 copper layers, 295.2 x 129.9 mm, 324 parts (13 on the bottom side), 159 nets.
